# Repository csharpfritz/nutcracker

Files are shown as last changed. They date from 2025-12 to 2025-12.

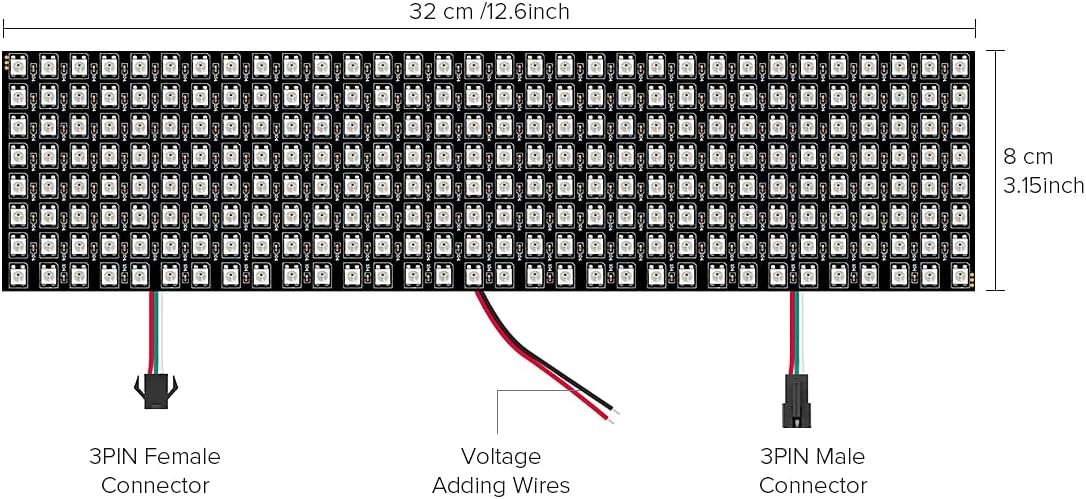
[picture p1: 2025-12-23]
matrix-dimensions.jpg

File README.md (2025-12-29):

# Nutcracker Holiday Display

A Blazor Server application for Raspberry Pi Zero that controls a holiday nutcracker decoration with a 32×8 WS2812B LED matrix and synchronized music playback. Features real-time LED lightshows, Bluetooth audio, and a web-based control UI.

## Features
- LED matrix animations synchronized to music
- Blazor Server web interface for control
- Raspberry Pi GPIO and native LED library integration
- Bluetooth audio playback
- Easily extensible with new lightshows and patterns

## Quick Start
1. See [DEPLOYMENT.md](docs/DEPLOYMENT.md) for build and deployment instructions.
2. Hardware setup and wiring: [raspberry-pi-gpio-diagram.md](docs/raspberry-pi-gpio-diagram.md)
3. LED pattern file format: [LED-PATTERN-FILE-FORMAT.md](docs/LED-PATTERN-FILE-FORMAT.md)
4. Lightshow design agent instructions: [LIGHTSHOW_AGENT_INSTRUCTIONS.md](docs/LIGHTSHOW_AGENT_INSTRUCTIONS.md)
5. Hardware shopping: [hardware-shopping-list.md](docs/hardware-shopping-list.md)

## Documentation
- [Session Notes](docs/SESSION-NOTES.md)
- [Deployment Guide](docs/DEPLOYMENT.md)
- [Raspberry Pi GPIO Diagram](docs/raspberry-pi-gpio-diagram.md)
- [LED Pattern File Format](docs/LED-PATTERN-FILE-FORMAT.md)
- [Lightshow Agent Instructions](docs/LIGHTSHOW_AGENT_INSTRUCTIONS.md)
- [LED Native Library](docs/LED-NATIVE-LIBRARY.md)
- [Enclosure Design Notes](docs/ENCLOSURE-DESIGN-NOTES.md)
- [Printer Sizing Notes](docs/PRINTER-SIZING-NOTES.md)
- [Hardware Shopping List](docs/hardware-shopping-list.md)

## 3D Print Schematics
All enclosure and display 3D models are in the [`schematics/`](schematics/) folder.

## Scripts
All music analysis and lightshow generation scripts are in the [`scripts/`](scripts/) folder.

## Contributing
See the docs above for architecture, hardware, and development workflow details. PRs and new lightshow patterns welcome!

---
Merry Christmas! 🎄

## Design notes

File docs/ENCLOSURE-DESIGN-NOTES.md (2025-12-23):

# Nutcracker Enclosure - Design Notes & Decisions

**Date Created:** 2025-12-23  
**Project:** Nutcracker Holiday Display  
**Designer:** AI Assistant + User Collaboration  

---

## Hardware Specifications

### Flexible LED Matrix
- **Dimensions:** 320mm (W) × 80mm (H) × 2mm (D)
- **Type:** Flexible WS2812B 8×32 matrix
- **Source:** Physical measurement from `matrix-dimensions.jpg`
- **Connectors:** 
  - 3PIN Female connector (left)
  - 3PIN Male connector (right)
  - Voltage Adding Wires (center)

### Raspberry Pi Zero
- **Dimensions:** 65mm (W) × 30mm (L) × 5mm (H)
- **Purpose:** Control system running Blazor Server app
- **GPIO:** Controls LED matrix via GPIO pins

### USB Battery Pack
- **Dimensions:** 60mm (W) × 90mm (L) × 15mm (H)
- **Purpose:** Portable power supply

### 3D Printer
- **Model:** FlashForge AD5X
- **Build Volume:** 220mm × 220mm × 220mm
- **Constraint:** This is the PRIMARY design constraint

---

## Design Decisions

### 1. Curved vs Flat Display
**DECISION:** Use curved/wraparound display design

**Reasoning:**
- Flexible matrix is 320mm wide - too wide for 220mm print bed
- Matrix is flexible, can be curved without damage
- Curved design creates more interesting "wraparound" nutcracker effect
- Better viewing angles from multiple directions

**Implementation:**
- Cylindrical curve with 120mm radius
- Arc angle: ~153 degrees (calculated from 320mm arc length)
- Chord width: ~199mm (fits within 220mm bed)
- Arc depth: ~86mm forward projection

### 2. Component Layout
**DECISION:** Separate main box and curved display

**Main Box Contains:**
- USB battery pack (bottom layer)
- Raspberry Pi Zero (stacked above battery)
- All internal electronics
- Access ports for USB power and micro USB

**Curved Display Contains:**
- Channel to hold flexible LED matrix
- Internal support ribs every ~50mm
- Wire pass-through at bottom for data cables
- Mounting base to attach to main box

### 3. Printability Strategy
**DECISION:** Three separate printable parts

**Parts:**
1. **Main Box** - 96mm × 98mm × 25mm ✅ Fits bed
2. **Lid** - 96mm × 98mm × 2mm ✅ Fits bed  
3. **Curved Display** - 199mm × 86mm × 84mm ✅ Fits bed

All parts fit within FlashForge AD5X constraints.

### 4. Assembly Method
**DECISION:** Modular snap-fit with optional screw mounting

- Lid has internal lip that fits into main box
- Curved display has mounting base that attaches to front of main box
- Can use snap-fit or screws (configurable via `lid_type` parameter)
- Wire management through dedicated pass-through holes

---

## Key Parameters (in SCAD file)

### Matrix Configuration
```openscad
led_matrix_width = 320;     // 32cm measured
led_matrix_height = 80;     // 8cm measured
led_matrix_depth = 2;       // Very thin, flexible
```

### Curve Configuration
```openscad
use_curved_display = true;  // Enable curved design
curve_radius = 120;         // Radius in mm (adjustable)
curve_segments = 60;        // Resolution for smooth curve
```

### Box Sizing
```openscad
wall_thickness = 2;         // Standard wall thickness
component_spacing = 3;      // Air gap between components
```

---

## Design Features

### Main Box
- ✅ Internal support ledges for battery and Pi Zero
- ✅ USB power port access (back wall)
- ✅ Micro USB access for Pi (side wall)
- ✅ Ventilation slots on sides
- ✅ Mounting holes in corners (3mm diameter)
- ✅ Bottom clearance for stability

### Curved Display
- ✅ Cylindrical channel to hold flexible matrix
- ✅ Internal ribs prevent matrix sagging
- ✅ Top, bottom, and side edge caps
- ✅ Wire pass-through opening (16mm wide)
- ✅ Mounting base with proper geometry
- ✅ Smooth arc using polygon generation

### Lid
- ✅ Internal lip for secure fit
- ✅ Ventilation hole pattern
- ✅ Optional screw mounting holes
- ✅ Thin profile (2mm + 3mm lip)

---

## Potential Adjustments Before Printing

### If Curve Is Too Tight/Loose
Adjust `curve_radius` parameter:
- **Smaller radius** (e.g., 100mm) = tighter curve, narrower width, MORE curved
- **Larger radius** (e.g., 150mm) = gentler curve, wider width, LESS curved
- **Current:** 120mm provides good balance

### If Parts Don't Fit Bed
- All parts currently fit within 220mm constraint
- If issues arise, can split curved display vertically into two halves

### If Matrix Doesn't Stay in Channel
- Increase internal support ribs (change spacing from 50mm to 30mm)
- Add friction strips or texture to channel surface
- Adjust `led_matrix_depth` if matrix is thicker than 2mm

### If Need Different Viewing Angle
- Original design had `display_tilt_angle = 15°` for flat plaque
- Curved design naturally provides viewing angle range
- Can modify curve center position if needed

---

## Assembly Notes

### Order of Assembly
1. Print all three parts
2. Install battery pack in main box (bottom)
3. Install Raspberry Pi Zero above battery
4. Route power cables through internal space
5. Attach lid to main box (snap or screw)
6. Insert flexible matrix into curved display channel
7. Route data cables from Pi through wire pass-through
8. Attach curved display to front of main box

### Connection Points
- **Power:** USB battery → Pi Zero via micro USB
- **Data:** Pi Zero GPIO → LED matrix 3PIN connector
- **Wiring Route:** Through wire pass-through at bottom of curved display

---

## Files Reference

- **3D Model:** `Nutcracker\wwwroot\nutcracker-enclosure.scad`
- **Matrix Specs:** `matrix-dimensions.jpg`
- **This Document:** `Nutcracker\wwwroot\ENCLOSURE-DESIGN-NOTES.md`

---

## Future Considerations

### Possible Enhancements
- Add diffuser panel in front of LEDs for better light blending
- Create mounting brackets to attach to nutcracker figure
- Add handle or hanging loop for portability
- Design cable management clips inside main box
- Add power switch cutout if battery doesn't have external switch

### Testing Recommendations
1. Print curved display first to test matrix fit
2. Test fit matrix in channel before printing other parts
3. Verify wire routing before final assembly
4. Check that all access ports align with actual hardware

---

## Questions to Resolve Before Printing

- [ ] Is the curve radius (120mm) acceptable? Want more/less curve?
- [ ] Do you want screw mounting or snap-fit? (Currently set to snap)
- [ ] Need any specific mounting features for attaching to nutcracker?
- [ ] Want a diffuser panel in front of LEDs?
- [ ] Need power switch access cutout?
- [ ] Any specific cable routing requirements?

---

## OpenSCAD Rendering Instructions

### For Print Layout (current setting)
All parts laid flat, ready for slicing:
```openscad
main_box();
translate([box_width + 10, 0, 0]) lid();
translate([110, box_length + 60, 0]) curved_display();
```

### For Assembly Preview
To see how parts fit together, comment out print layout and uncomment:
```openscad
// main_box();
// translate([0, 0, box_height]) lid();
// translate([box_width/2, -curve_arc_depth, box_height]) curved_display();
```

---

**Status:** Design complete, ready for review before printing  
**Next Step:** Review this document, ask questions, make adjustments as needed

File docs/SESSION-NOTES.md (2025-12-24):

# Nutcracker LED Display - Session Notes
**Last Updated:** December 23, 2024 11:41 PM EST

## Project Overview
Blazor Server application running on Raspberry Pi Zero controlling a holiday nutcracker decoration with LED matrix and Bluetooth audio.

## Hardware Configuration

### Raspberry Pi Details
- **Hostname:** `nutcracker-2`
- **SSH Access:** `jfritz@nutcracker-2`
- **User:** jfritz
- **Deployment Path:** `/home/jfritz/www/`
- **Service:** `nutcracker.service` (systemd service, runs with sudo)

### LED Matrix Configuration
- **Type:** WS2812B addressable RGB LED strip
- **Total LEDs:** 256 (8 rows × 32 columns)
- **GPIO Pin:** 10 (SPI0 MOSI - Physical Pin 19)
- **DMA Channel:** 10
- **Frequency:** 800kHz
- **Current Brightness:** 80% (204/255) - reduced from 100% to be easier on eyes

### LED Matrix Wiring Pattern
- **Layout:** 8 rows tall × 32 columns wide
- **Wiring:** Serpentine/zigzag pattern
- **LED 0 Position:** Top-left corner
- **Pattern:**
  - Column 0 (LEDs 0-7): Goes DOWN from top to bottom
  - Column 1 (LEDs 8-15): Goes UP from bottom to top (serpentine)
  - Column 2 (LEDs 16-23): Goes DOWN again
  - Pattern continues alternating
- **Coordinate Conversion Function:**
  ```python
  def xy_to_led(x, y, width=32, height=8):
      if x % 2 == 0:  # Even columns go down
          return x * 8 + y
      else:  # Odd columns go up
          return x * 8 + (7 - y)
  ```

### Audio Configuration
- **Output:** Bluetooth speaker
- **Device:** B19 Pro (MAC: 46:5A:8F:27:9F:4D)
- **Status:** Connected and paired
- **Default Sink:** `bluez_output.46_5A_8F_27_9F_4D.1` (PulseAudio/PipeWire)
- **System Volume:** 73% (controlled via amixer)
- **Player:** mplayer (requires TERM=dumb and PULSE_SERVER environment variables to work in systemd service)

## Application Structure

### Key Files
- **Main Service:** `Nutcracker/Services/LightshowService.cs` - Manages queue and playback
- **LED Control:** `Nutcracker/Services/LedService.cs` - Controls LED hardware
- **Native Library:** `Nutcracker/Services/Ws2811Native.cs` - P/Invoke to libws2811.so
- **UI:** `Nutcracker/Components/Pages/Home.razor` - Web interface
- **Music Files:** `wwwroot/music/*.mp3`
- **Light Patterns:** `wwwroot/lights/*.json`

### Deployment Process
1. Stop service: `ssh jfritz@nutcracker-2 "sudo systemctl stop nutcracker"`
2. Build on Windows: `dotnet publish -c Release` (from D:\Nutcracker)
3. Files auto-deploy to Pi (configured in project)
4. Start service: `ssh jfritz@nutcracker-2 "sudo systemctl start nutcracker"`

### Service Management
- **View logs:** `ssh jfritz@nutcracker-2 "sudo journalctl -u nutcracker --no-pager -n 50"`
- **Status:** `ssh jfritz@nutcracker-2 "sudo systemctl status nutcracker --no-pager"`
- **Stop:** `ssh jfritz@nutcracker-2 "sudo systemctl stop nutcracker"`
- **Start:** `ssh jfritz@nutcracker-2 "sudo systemctl start nutcracker"`
- **Restart:** `ssh jfritz@nutcracker-2 "sudo systemctl restart nutcracker"`

## Current LED Patterns

### Idle Display: "MERRY" Text
**File:** `wwwroot/lights/merry-christmas-static.json`

**Design:**
- Red text "MERRY" centered vertically (rows 1-6)
- Green border lines at top (row 0) and bottom (row 7)
- Black background everywhere else
- Font: 3x5 pixel letters with 1-column spacing between letters
- Static display (holds for 5 minutes before looping)

### Enhancement: Full "MERRY CHRISTMAS" Scrolling Idle Display
**Goal:** Extend the idle display so it shows the full phrase "MERRY CHRISTMAS" scrolling right-to-left across the matrix, rather than only "MERRY". The scroll should be smooth, readable, and repeat indefinitely.

**Why:** The full phrase is more festive for viewers and leverages the existing 32×8 matrix by scrolling text across rather than fitting a shorter centered word.

**Acceptance Criteria:**
- The full text "MERRY CHRISTMAS" scrolls from right-to-left and repeats infinitely.
- Text is red, vertically centered on rows 1-6, with 1-column spacing between letters using the 3x5 font.
- Top and bottom green borders remain visible during scrolling.
- Default scroll speed is readable (approx. 120ms/column) and configurable via the JSON pattern.
- LightshowService falls back to `merry-christmas-static.json` if the scrolling file is missing.

**Implementation Steps:**
1. Verify `wwwroot/lights/merry-christmas-scrolling.json` contains a `scrollMs` parameter and frames representing a full cycle (text width + display width).
2. If not present, generate the JSON: render the text into a bitmap (width = text pixel width), produce frames shifting the bitmap left by one column per `scrollMs`, and add border frames for top/bottom green rows.
3. Ensure frames use `set` and `clear` effects with exact LED indices computed via `xy_to_led(x, y)` to match serpentine wiring.
4. Update `LightshowService.cs` (optional) to use `merry-christmas-scrolling.json` as the idle pattern when queue is empty.
5. Deploy and test on Pi using the web UI "Test LEDs" and by running the service.

**Quick Test Commands:**
```bash
# On the Pi - test pattern file exists
ls -la /home/jfritz/www/wwwroot/lights/merry-christmas-scrolling.json

# Trigger a test from the web UI or restart the service after deploy
sudo systemctl restart nutcracker
sudo journalctl -u nutcracker --no-pager -n 100
```

**Notes:** If the Pi Zero struggles with rendering many frames at `120ms` per column, increase `scrollMs` to reduce CPU load or precompute fewer frames and loop them.

**LED Mappings:**
- **Red LEDs (MERRY):** [9, 10, 11, 12, 13, 14, 18, 25, 26, 27, 28, 29, 30, 41, 42, 43, 44, 45, 46, 49, 51, 54, 57, 62, 73, 74, 75, 76, 77, 78, 81, 83, 89, 90, 91, 93, 94, 105, 106, 107, 108, 109, 110, 113, 115, 121, 122, 123, 125, 126, 140, 141, 142, 148, 149, 150, 156, 157, 158]
- **Green LEDs (borders):** [0, 7, 8, 15, 16, 23, 24, 31, 32, 39, 40, 47, 48, 55, 56, 63, 64, 71, 72, 79, 80, 87, 88, 95, 96, 103, 104, 111, 112, 119, 120, 127, 128, 135, 136, 143, 144, 151, 152, 159, 160, 167, 168, 175, 176, 183, 184, 191, 192, 199, 200, 207, 208, 215, 216, 223, 224, 231, 232, 239, 240, 247, 248, 255]

### Light Pattern JSON Format
```json
{
  "name": "Pattern Name",
  "description": "Description",
  "durationMs": 300000,
  "frames": [
    {
      "timestampMs": 0,
      "effect": "fill|set|clear|gradient",
      "color": "#RRGGBB",
      "leds": [array of LED indices]
    }
  ]
}
```

## Issues Fixed This Session

### 1. LED Matrix Wiring Discovery
**Problem:** Text displaying as scattered LEDs, unreadable  
**Solution:** Tested matrix with Python scripts to determine serpentine wiring pattern, created xy_to_led() conversion function  
**Testing Script Location:** `/tmp/test_merry5.py` on Pi (various test scripts created)

### 2. LED Brightness Too High
**Problem:** LEDs hurt eyes at full brightness  
**Solution:** Changed `DEFAULT_BRIGHTNESS` from 255 to 204 (80%) in LedService.cs line 24

### 3. Music Not Playing Through Bluetooth
**Problem:** mplayer process exiting immediately when run as systemd service  
**Root Cause:** Missing TERM environment variable and PulseAudio server path  
**Solution:** Added to LightshowService.cs ProcessStartInfo:
```csharp
Environment = 
{
    ["TERM"] = "dumb",
    ["PULSE_SERVER"] = "unix:/run/user/1000/pulse/native"
}
```

### 4. Skip Button Not Working
**Problem:** Skip button in UI not stopping music playback  
**Root Cause 1:** Added `ReadToEndAsync()` on stderr which blocked until process ended  
**Root Cause 2:** Cancellation didn't kill the mplayer process  
**Solution:** 
- Removed blocking stderr read
- Added process.Kill() in OperationCanceledException catch block (LightshowService.cs lines 179-192)

### 5. Pattern Blinking Rapidly
**Problem:** LED pattern looping every 100ms causing seizure-inducing flashing  
**Solution:** Added dummy frame at 299900ms to make pattern static for 5 minutes

## Available Lightshows
Located in `LightshowService.cs` AvailableLightshows array:
1. Santa Claus Is Comin To Town (4:28) - Bruce Springsteen
2. Deck the Halls (1:14)
3. Grandma Got Run Over By A Reindeer (3:24) - Elmo & Patsy
4. Rudolph the Red-Nosed Reindeer (3:08) - Gene Autry
5. Hark the Herald Angels Sing (4:41) - Celtic Christmas
6. Joy to the World (2:03)
7. O Come All Ye Faithful (5:22) - Celtic Christmas
8. Oh Christmas Tree (1:41)
9. Santa Claus Is Coming to Town (Piano) (1:49)
10. Silent Night (2:51)
11. Wizards in Winter (3:05) - Trans-Siberian Orchestra

**Note:** Most songs are missing light pattern JSON files (only merry-christmas-static.json exists currently)

## Testing LED Patterns

### Quick Test Script Template (Python)
```python
#!/usr/bin/env python3
import time, ctypes

lib = ctypes.CDLL('/usr/local/lib/libws2811.so')

# [Structure definitions omitted for brevity - see test_merry5.py]

def xy_to_led(x, y):
    if x < 0 or x >= 32 or y < 0 or y >= 8:
        return None
    if x % 2 == 0:
        return x * 8 + y
    else:
        return x * 8 + (7 - y)

# Create pattern, set pixels, show()
```

**Process:**
1. SSH to Pi: `ssh jfritz@nutcracker-2`
2. Stop service: `sudo systemctl stop nutcracker`
3. Create script: `cat > /tmp/test.py << 'EOF' ... EOF`
4. Run: `sudo python3 /tmp/test.py`
5. Restart service: `sudo systemctl start nutcracker`

## Web Interface
- **URL:** `http://nutcracker-2:3000` or `http://<pi-ip>:3000`
- **Features:**
  - Now Playing display with song name and duration
  - Volume slider (0-100%)
  - LED Brightness slider (0-100%)
  - Skip button (✓ working as of this session)
  - Queue display ("Up Next")
  - Available songs grid with "Add to Queue" buttons
  - Settings section with "Test LEDs" button

## Known Issues / TODO

### Missing Light Patterns
Most songs don't have light pattern JSON files yet. Currently using fallback animation (moving wave, pulsing, row/column scans).

Pattern files needed:
- santa-claus-is-comin-to-town.json
- deck-the-halls.json
- grandma-got-run-over.json
- rudolph.json
- hark-the-herald.json
- joy-to-the-world.json
- o-come-all-ye-faithful.json
- oh-christmas-tree.json
- santa-claus-piano.json
- silent-night.json
- wizards-in-winter.json

### Path Issue in Logs
Logs show: `Pattern file not found: /home/jfritz/www/wwwroot/wwwroot/lights/...`
Notice the double `wwwroot/wwwroot` - may need to fix path resolution in LedService.cs

## Useful Commands Reference

### Testing Audio
```bash
# Test Bluetooth connection
bluetoothctl devices
bluetoothctl info 46:5A:8F:27:9F:4D

# Check audio sinks
pactl list sinks short
pactl get-default-sink

# Check volume
amixer sget Master

# Test mplayer manually
cd /home/jfritz/www
mplayer -volume 70 -ao pulse "wwwroot/music/deck-the-halls-christmas-bells-129141.mp3"
```

### Testing LEDs
```bash
# Quick LED test (light up LED 0 red for 5 seconds)
sudo python3 << 'EOF'
import time, ctypes
lib = ctypes.CDLL('/usr/local/lib/libws2811.so')
# [Full test code in test scripts]
EOF
```

### File Management
```bash
# Check music files
ls -la /home/jfritz/www/wwwroot/music/

# Check light patterns
ls -la /home/jfritz/www/wwwroot/lights/

# Edit pattern file on Pi
nano /home/jfritz/www/wwwroot/lights/merry-christmas-static.json

# Copy pattern from Windows to Pi
scp "D:\Nutcracker\Nutcracker\wwwroot\lights\*.json" jfritz@nutcracker-2:/home/jfritz/www/wwwroot/lights/
```

## Code Architecture Notes

### LightshowService Pattern
- Runs as BackgroundService (ExecuteAsync loop)
- Maintains ConcurrentQueue of lightshows
- When queue empty, plays idle "Merry Christmas" static pattern
- When show queued, stops idle and starts show (music + LED pattern)
- Uses CancellationTokenSource for skip functionality
- Volume control via amixer (system-wide)

### LedService Pattern
- Singleton service
- Uses native libws2811.so via P/Invoke (Ws2811Native.cs)
- Supports matrix operations via row/col coordinates
- Pattern playback via JSON files
- Fallback animations if pattern file missing

### LED Pattern Frame Effects
- **fill:** Set all LEDs to one color
- **set:** Set specific LED indices to a color
- **clear:** Turn off specific LEDs
- **gradient:** Gradient between two colors across LED indices

## Development Workflow
1. Make changes on Windows in Visual Studio / VS Code
2. Stop Pi service via SSH
3. Build: `dotnet publish -c Release` (auto-deploys)
4. Start Pi service via SSH
5. Test via web interface at http://nutcracker-2:3000
6. Check logs if issues: `sudo journalctl -u nutcracker -n 50`

## Success Metrics This Session
✅ LED matrix wiring pattern identified and documented  
✅ "MERRY" text displaying correctly with clean design  
✅ Music playing through Bluetooth speaker  
✅ Skip button fully functional  
✅ Brightness reduced to comfortable level (80%)  
✅ Pattern stable without blinking  
✅ System documented for future sessions  
✅ Full "MERRY CHRISTMAS" scrolling text implemented  
✅ Optimized LED pattern playback to eliminate blinking (182 frames, batched updates)  
✅ Proper serpentine wiring pattern support in scrolling text

## Next Steps / Future Work
- [ ] Create light patterns for remaining songs
- [ ] Fix double wwwroot path issue
- [ ] Add more text patterns (XMAS, HAPPY HOLIDAYS, etc.)
- [ ] Consider adding animation patterns (snowflakes, candy canes, etc.)
- [ ] Add schedule/timer functionality for auto-play
- [ ] Motion sensor integration to trigger shows
- [ ] Multiple display patterns/themes

---

## Quick Start for Next Session

1. **Verify system status:**
   ```bash
   ssh jfritz@nutcracker-2 "sudo systemctl status nutcracker"
   ```

2. **Test pattern is still working:**
   - Visit http://nutcracker-2:3000
   - Should see "MERRY" in red with green borders

3. **Test music and skip:**
   - Add song to queue
   - Verify music plays
   - Click skip button to verify it works

4. **Development environment:**
   - Open `D:\Nutcracker` in your IDE
   - Key files: LightshowService.cs, LedService.cs, Home.razor
   - Deploy: `dotnet publish -c Release`

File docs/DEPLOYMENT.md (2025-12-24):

# Nutcracker Deployment Guide

## Quick Deployment (Recommended)

### Incremental Deployment
Use the automated deployment scripts for faster deployments that only upload changed files:

**Windows (PowerShell):**
```bash
.\deploy.ps1
```

**Linux/Mac:**
```bash
./deploy.sh
```

**Options:**
- `--clean` / `-Clean`: Clean rebuild before deployment
- `--skip-build` / `-SkipBuild`: Skip build, deploy existing files only
- `--target` / `-Target`: Target Pi address (default: nutcracker-2)
- `--user` / `-User`: SSH username (default: jfritz)
- `--path` / `-Path`: Remote deployment path (default: /home/jfritz/www)

**Examples:**
```bash
# Standard deployment
.\deploy.ps1

# Clean rebuild and deploy
.\deploy.ps1 -Clean

# Deploy to different Pi
.\deploy.ps1 -Target "192.168.1.100" -User "pi" -Path "/home/pi/nutcracker"

# Deploy only (skip build)
.\deploy.ps1 -SkipBuild
```

### Benefits of Incremental Deployment
- **Fast**: Only uploads changed files (using rsync)
- **Efficient**: Compresses data during transfer
- **Safe**: Automatically restarts service after deployment
- **Smart**: Excludes debug files and development configs

## Manual Deployment

### 1. Build and Deploy
```bash
cd Nutcracker
dotnet publish -c Release
# Uses MSBuild target to automatically deploy via scripts above
```

### 2. Manual SCP (Not Recommended)
```bash
cd Nutcracker
dotnet publish -c Release -r linux-arm64 --self-contained
scp -r bin/Release/net10.0/linux-arm64/publish/* jfritz@nutcracker-2:/home/jfritz/www/
```

### 4. Set Up Auto-Start (Optional)
Create a systemd service:
```bash
sudo nano /etc/systemd/system/nutcracker.service
```

Contents:
```ini
[Unit]
Description=Nutcracker Holiday Display
After=network.target

[Service]
Type=simple
User=root
WorkingDirectory=/home/pi/nutcracker
ExecStart=/home/pi/nutcracker/Nutcracker
Restart=on-failure
RestartSec=10

[Install]
WantedBy=multi-user.target
```

Enable and start:
```bash
sudo systemctl daemon-reload
sudo systemctl enable nutcracker
sudo systemctl start nutcracker
```

View logs:
```bash
sudo journalctl -u nutcracker -f
```

## LED Hardware Permissions

The rpi_ws281x library requires elevated permissions to access DMA and GPIO hardware.

### Option 1: Run with sudo (Quick Testing)
```bash
cd /home/jfritz/www
sudo ./Nutcracker
```

### Option 2: Use systemd service (Recommended)
The service configuration above runs as root automatically. Just use:
```bash
sudo systemctl restart nutcracker
sudo journalctl -u nutcracker -f
```

### Option 3: Set Linux Capabilities (Most Secure)
Allow LED control without full root privileges:
```bash
# Upload the capability script
scp set_capabilities.sh jfritz@nutcracker-2:/home/jfritz/www/

# Run it on the Pi
ssh jfritz@nutcracker-2
cd /home/jfritz/www
chmod +x set_capabilities.sh
./set_capabilities.sh

# Now you can run without sudo
./Nutcracker
```

**Note:** Capabilities are lost when the binary is replaced, so re-run `set_capabilities.sh` after each deployment if using this method.

## Verify Installation

Check library is installed:
```bash
ls -l /usr/local/lib/libws2811.so
```

Check application has permissions:
```bash
getcap ./Nutcracker
# Should show: cap_dma,cap_sys_admin=ep
```

Test GPIO access:
```bash
sudo ./Nutcracker --urls http://0.0.0.0:5000
# Should see "LED strip initialized successfully" in logs
```

## Testing Without Full Deploy

Quick test with Python script:
```bash
python3 led_matrix_test.py
```

This verifies:
- Hardware wiring is correct
- GPIO 18 is accessible
- LED strip is functioning
- Power supply is adequate

## Common Issues

**"libws2811.so not found"**
```bash
# Make sure it's in the library path
sudo ldconfig
ls -l /usr/local/lib/libws2811.so
```

**"Permission denied" or "Cannot access /dev/mem"**
```bash
# Run with sudo or set capabilities
sudo ./Nutcracker
```

**LEDs don't light up but no errors**
- Check power supply (most common issue)
- Verify GPIO 18 connection
- Try the Python test script to verify hardware
- Check LED strip color order (GRB vs RGB)

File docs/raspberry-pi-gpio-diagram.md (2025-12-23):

# Raspberry Pi GPIO Pin Diagram for WS2812B LED Strip

## Pin Layout (40-pin GPIO header)

```
     3V3  (1) (2)  5V
   GPIO2  (3) (4)  5V
   GPIO3  (5) (6)  GND
   GPIO4  (7) (8)  GPIO14
     GND  (9) (10) GPIO15
  GPIO17 (11) (12) GPIO18  ← **DATA PIN FOR LEDs**
  GPIO27 (13) (14) GND
  GPIO22 (15) (16) GPIO23
     3V3 (17) (18) GPIO24
  GPIO10 (19) (20) GND
   GPIO9 (21) (22) GPIO25
  GPIO11 (23) (24) GPIO8
     GND (25) (26) GPIO7
   GPIO0 (27) (28) GPIO1
   GPIO5 (29) (30) GND
   GPIO6 (31) (32) GPIO12
  GPIO13 (33) (34) GND
  GPIO19 (35) (36) GPIO16
  GPIO26 (37) (38) GPIO20
     GND (39) (40) GPIO21
```

## WS2812B LED Strip Connections

### Required Connections:
1. **VCC (Red wire)** → **Pin 2 (5V)** or **Pin 4 (5V)**
2. **GND (Black/White wire)** → **Pin 6 (GND)**, **Pin 9 (GND)**, **Pin 14 (GND)**, **Pin 20 (GND)**, **Pin 25 (GND)**, **Pin 30 (GND)**, **Pin 34 (GND)**, or **Pin 39 (GND)**
3. **DIN/Data (Green wire)** → **Pin 12 (GPIO18)**

### Physical Pin Layout Visual:
```
[3V3] [5V ]  ← Pin 1, 2
[GP2] [5V ]  ← Pin 3, 4
[GP3] [GND]  ← Pin 5, 6
[GP4] [G14]  ← Pin 7, 8
[GND] [G15]  ← Pin 9, 10
[G17] [G18]  ← Pin 11, 12 (GPIO18 = DATA)
[G27] [GND]  ← Pin 13, 14
[G22] [G23]  ← Pin 15, 16
[3V3] [G24]  ← Pin 17, 18
[G10] [GND]  ← Pin 19, 20
[GP9] [G25]  ← Pin 21, 22
[G11] [GP8]  ← Pin 23, 24
[GND] [GP7]  ← Pin 25, 26
```

## Troubleshooting Checklist:

### Power Issues:
- **LED strip not lighting at all**: Check 5V and GND connections
- **LEDs dim or flickering**: 5V power supply may be insufficient for your strip length
- **Only first few LEDs work**: Power supply can't handle full strip current draw

### Data Issues:
- **No response to commands**: Check GPIO18 (Pin 12) connection to DIN
- **Random colors/patterns**: Loose data connection or interference
- **Only first LED works**: Data signal not passing through strip properly

### Wire Colors (Common):
- **Red** = VCC (5V power)
- **Black/White** = GND (Ground)
- **Green/Yellow** = DIN (Data Input)

### Important Notes:
1. **GPIO18** is the **PWM-capable pin** - best for WS2812B timing
2. Use **Pin 12** (not pin 18 - that's GPIO24!)
3. Make sure connections are secure - breadboard jumpers can be loose
4. Test with a multimeter if possible:
   - 5V between VCC and GND
   - 3.3V between GPIO18 and GND when Pi is running

### Alternative Data Pins:
If GPIO18 doesn't work, you can try:
- **GPIO10** (Pin 19) - SPI MOSI
- **GPIO21** (Pin 40) - PCM
- **GPIO12** (Pin 32) - PWM

Update the code to use a different pin:
```python
pixels = neopixel.NeoPixel(board.D21, 256, brightness=0.1, auto_write=False)  # GPIO21
```

### Common Connection Mistakes:
1. Using **Pin 18** instead of **Pin 12** (Pin 18 is GPIO24, not GPIO18!)
2. Connecting to 3.3V instead of 5V (LEDs need 5V)
3. Loose ground connection
4. Reversed polarity on LED strip

### LED Strip Direction:
- Connect to the **input end** of the strip (usually has arrows showing data direction)
- Look for **DIN** (Data In) not **DOUT** (Data Out)

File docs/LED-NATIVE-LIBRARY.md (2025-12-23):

# LED Control with Native rpi_ws281x Library

This project uses P/Invoke to call the native `rpi_ws281x` library directly from C#, providing full control over WS2812B LED strips with precise timing.

## Why Native Library?

The Python test script (`led_matrix_test.py`) works because it uses the `rpi_ws281x` library (via Adafruit NeoPixel), which provides hardware-accurate PWM timing for WS2812B LEDs. The previous C# approach using SPI didn't work reliably because:

1. **WS2812B requires precise PWM timing** (350ns/700ns pulses)
2. **SPI protocol doesn't match WS2812B timing** requirements
3. **The native library uses DMA + PWM** for accurate signal generation

## Architecture

```
C# Application (LedService.cs)
    ↓ P/Invoke
Ws2811Native.cs (P/Invoke wrapper)
    ↓ Native calls
libws2811.so (Native C library)
    ↓ Hardware control
GPIO 18 (PWM0) → WS2812B LED Strip
```

## Installation on Raspberry Pi

### 1. Install the Native Library

Run the installation script:
```bash
chmod +x install_native_led_library.sh
./install_native_led_library.sh
```

This will:
- Clone and build the `rpi_ws281x` library
- Install `libws2811.so` to `/usr/local/lib/`
- Set up proper library paths

### 2. Grant Permissions

The application needs DMA and hardware access. Either:

**Option A: Run with sudo** (simplest)
```bash
sudo ./Nutcracker
```

**Option B: Set capabilities** (more secure)
```bash
sudo setcap 'cap_dma=ep cap_sys_admin=ep' ./Nutcracker
./Nutcracker
```

## Hardware Connection

```
Raspberry Pi         WS2812B LED Strip
----------------------------------------
GPIO 18 (Pin 12) --> DIN (Data Input)
5V Power         --> VCC (or use external 5V supply)
Ground           --> GND
```

**Important Notes:**
- GPIO 18 is the PWM0 pin (Physical Pin 12)
- For many LEDs, use an external 5V power supply
- Add a 300-470 ohm resistor between GPIO 18 and DIN
- Add a 1000µF capacitor across power supply

## Configuration

Edit `LedService.cs` constants if needed:

```csharp
private const int GPIO_PIN = 18;        // GPIO pin
private const int DMA_CHANNEL = 10;     // DMA channel (10 is safe)
private const uint TARGET_FREQ = 800000; // 800kHz for WS2812B
private const byte DEFAULT_BRIGHTNESS = 255; // 0-255
```

### LED Strip Color Order

Most WS2812B use GRB order, but if colors are wrong:
```csharp
strip_type = (int)WS2811_STRIP_GRB  // Default (Green, Red, Blue)
// Or try:
strip_type = (int)WS2811_STRIP_RGB  // Red, Green, Blue
strip_type = (int)WS2811_STRIP_BGR  // Blue, Green, Red
```

## Development

The service automatically detects if running on Raspberry Pi:
- **Linux ARM**: Uses native library
- **Other platforms**: Uses mock mode (logs only)

## Library Reference

- **Source**: https://github.com/jgarff/rpi_ws281x
- **Documentation**: See `ws2811.h` in the repository
- **Library location**: `/usr/local/lib/libws2811.so`

## Troubleshooting

### "Failed to initialize LED strip"
1. Make sure library is installed: `ls -l /usr/local/lib/libws2811.so`
2. Run with sudo: `sudo ./Nutcracker`
3. Check GPIO is not in use: `sudo fuser /dev/gpiomem`

### Colors are wrong
Change the `strip_type` in `LedService.cs` initialization

### LEDs flicker or show wrong colors
- Check power supply (insufficient power is common)
- Verify wiring and connections
- Reduce brightness in code

### DllNotFoundException
The library isn't installed. Run `install_native_led_library.sh`

## Performance

The native library provides:
- **Precise timing**: Hardware PWM + DMA
- **High frame rates**: 60+ FPS easily achievable
- **Low CPU usage**: DMA handles data transfer
- **Reliable operation**: Same code Python uses

## Comparison with Python

| Aspect | Python (rpi_ws281x) | C# (P/Invoke) |
|---|---|---|
| Library | Python wrapper | Direct P/Invoke |
| Performance | Good | Excellent |
| Control | High-level API | Full control |
| Integration | External process | Native |
| Timing | Library-controlled | Library-controlled |

Both use the same underlying native library, so reliability is identical!

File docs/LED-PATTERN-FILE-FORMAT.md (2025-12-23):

# LED Pattern File Format

LED pattern files define the light animations for the 8x32 LED matrix. Patterns are stored as JSON files in this directory.

## Matrix Layout

- **Dimensions**: 8 rows × 32 columns = 256 LEDs total
- **GPIO Pin**: 10 (SPI0 MOSI)
- **LED Indexing**: 0-255 (0 = top-left, 31 = top-right, 32 = second row left, etc.)
- **LED Type**: WS2812B/NeoPixel addressable LEDs
- **Interface**: SPI (requires SPI to be enabled on Raspberry Pi)

## Pattern File Structure

```json
{
  "name": "Pattern Name",
  "description": "Brief description of the pattern",
  "durationMs": 10000,
  "frames": [
    // Array of frames with timestamps
  ]
}
```

### Properties

- **name**: Human-readable name for the pattern
- **description**: Optional description of what the pattern does
- **durationMs**: Total duration of the pattern in milliseconds
- **frames**: Array of LED frames to display over time

## Frame Structure

Each frame defines what should happen at a specific timestamp.

```json
{
  "timestampMs": 0,
  "effect": "set",
  "color": "#FF0000",
  "leds": [0, 1, 2, 3]
}
```

### Frame Properties

- **timestampMs**: When to display this frame (milliseconds from start)
- **effect**: Type of effect to apply (see below)
- **color**: Hex color code (e.g., "#FF0000" for red)
- **leds**: Array of LED indices to affect (optional, depends on effect)
- **startColor**: Start color for gradient effects
- **endColor**: End color for gradient effects

## Effect Types

### 1. **set** - Set specific LEDs to a color

```json
{
  "timestampMs": 100,
  "effect": "set",
  "color": "#FF0000",
  "leds": [0, 1, 2, 3, 4, 5]
}
```

### 2. **fill** - Fill all LEDs with a color

```json
{
  "timestampMs": 200,
  "effect": "fill",
  "color": "#00FF00"
}
```

### 3. **clear** - Turn off LEDs

```json
{
  "timestampMs": 300,
  "effect": "clear",
  "leds": [0, 1, 2, 3]  // Optional: specific LEDs, omit to clear all
}
```

### 4. **gradient** - Apply a color gradient across LEDs

```json
{
  "timestampMs": 400,
  "effect": "gradient",
  "startColor": "#FF0000",
  "endColor": "#0000FF",
  "leds": [0, 32, 64, 96, 128, 160, 192, 224]  // Top row of each column
}
```

## Color Format

Colors use 6-digit hex format:
- `#FF0000` - Red
- `#00FF00` - Green
- `#0000FF` - Blue
- `#FFFFFF` - White
- `#000000` - Black (off)
- `#FFA500` - Orange
- `#800080` - Purple

## LED Index Mapping

### Row-by-row indexing:
```
Row 0:   0- 31  (top row)
Row 1:  32- 63
Row 2:  64- 95
Row 3:  96-127
Row 4: 128-159
Row 5: 160-191
Row 6: 192-223
Row 7: 224-255  (bottom row)
```

### Helper formulas:
- LED at (row, col) = `row * 32 + col`
- Row of LED = `index / 32`
- Column of LED = `index % 32`

## Example Patterns

### Simple Chase

```json
{
  "name": "Red Chase",
  "description": "Red light chasing across the matrix",
  "durationMs": 3200,
  "frames": [
    { "timestampMs": 0, "effect": "fill", "color": "#000000" },
    { "timestampMs": 100, "effect": "set", "color": "#FF0000", "leds": [0] },
    { "timestampMs": 200, "effect": "set", "color": "#FF0000", "leds": [1] },
    { "timestampMs": 300, "effect": "set", "color": "#FF0000", "leds": [2] }
    // ... continue for all LEDs
  ]
}
```

### Rainbow Wave

```json
{
  "name": "Rainbow Wave",
  "description": "Rainbow gradient moving across columns",
  "durationMs": 5000,
  "frames": [
    {
      "timestampMs": 0,
      "effect": "gradient",
      "startColor": "#FF0000",
      "endColor": "#FF00FF",
      "leds": [0, 32, 64, 96, 128, 160, 192, 224]
    },
    {
      "timestampMs": 100,
      "effect": "gradient",
      "startColor": "#FF0000",
      "endColor": "#FF00FF",
      "leds": [1, 33, 65, 97, 129, 161, 193, 225]
    }
    // ... continue for all columns
  ]
}
```

### Strobe Effect

```json
{
  "name": "White Strobe",
  "description": "Strobing white light",
  "durationMs": 2000,
  "frames": [
    { "timestampMs": 0, "effect": "fill", "color": "#FFFFFF" },
    { "timestampMs": 100, "effect": "fill", "color": "#000000" },
    { "timestampMs": 200, "effect": "fill", "color": "#FFFFFF" },
    { "timestampMs": 300, "effect": "fill", "color": "#000000" }
  ]
}
```

## Tips

1. **Timing**: Frame timestamps should be synchronized with your music file
2. **Performance**: Limit frames to ~30-60 per second (16-33ms intervals) for smooth animation
3. **File Size**: Keep pattern files reasonable in size; consider repetitive patterns
4. **Testing**: Test patterns on the hardware to ensure timing accuracy
5. **Brightness**: LEDs can be very bright; consider using dimmer colors for indoor use

## Creating Patterns

You can create patterns by:
1. Hand-coding JSON files (for simple patterns)
2. Using a pattern generator script (future enhancement)
3. Recording LED states during a live performance
4. Converting music visualization data to LED patterns

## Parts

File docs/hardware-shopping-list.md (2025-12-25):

# Nutcracker Enclosure Hardware Shopping List

## Screws Needed from Home Depot

### 1. Lid Screws (4 needed)
- **#6 x ½" Phillips Pan Head Sheet Metal Screws** (stainless steel)
- **Purpose:** Securing the lid to the box base for battery access
- **Notes:** Thread into 3mm holes in the plastic. Self-tapping screws work best for PLA/PETG prints.

### 2. Display Mounting Screws (2 needed)
- **M3 x 10mm Phillips Pan Head Machine Screws** with nuts
- **Purpose:** Mounting the curved LED display to the front of the box
- **Notes:** Goes through display mounting tabs into the box. Install from inside the box.

### 3. Raspberry Pi Mounting Screws (4 needed)
- **M2.5 x 8mm Phillips Pan Head Screws** with nylon washers
- **Purpose:** Mounting the Raspberry Pi 3B to the standoffs inside the box
- **Notes:** Standard Pi mounting hardware. Often sold as "Raspberry Pi mounting kit" in electronics section.

### 4. Nutcracker Base Mounting Screws (4 needed)
- **M4 x 12mm or #8 x ½" Phillips Pan Head Screws** with washers
- **Purpose:** Mounting the nutcracker decoration to the top of the box
- **Notes:** 4mm holes in a 50mm x 70mm rectangular pattern. Use washers to distribute load.

## Assembly Notes

### Display Mounting Method
1. The curved LED display has a flat mounting base with two tabs
2. Tabs are positioned at ±¼ of the display width
3. M3 screws are inserted from inside the box through the front wall into the display tabs
4. Wire pass-through hole (16mm) allows LED cables to run from Pi to display

### LED Matrix Installation (No Glue Required!)
1. **Open curved backing** - The display has a curved back panel that the matrix rests against
2. **Support ribs** - Internal ribs every ~50mm provide backing support along the curve
3. **Installation:** 
   - Place the LED matrix onto the curved back panel with connectors facing outward
   - Arrange the power wires through the wire pass-through hole
   - Snap the removable clear cover over the front - it has spring clips at top and bottom edges
4. **Removable cover** - Clear curved front cover snaps on with 4 clips on each edge
5. **Connector clearance** - The open design allows the 3PIN connectors and wires on the back to exit freely
6. **Removal:** Pop off the snap-on cover to service or replace the LED matrix

### Battery Access
- Lid is secured with 4 corner screws (self-tapping sheet metal screws)
- Large cutout in lid provides direct access to battery compartment
- Remove 4 screws to access battery and connect power cables

### Hardware Pattern Summary
- **Nutcracker mounting:** 4 holes, 50mm x 60mm spacing (top of box) - **UPDATED to fit 2¾" x 2¹³⁄₁₆" nutcracker base**
- **Display mounting:** 2 holes on front wall
- **Pi mounting:** 4 holes, 58mm x 49mm standard Pi 3B pattern (inside box)
- **Lid mounting:** 4 corner holes

## Total Screw Count
- 14 screws total for nutcracker enclosure
- Optional: 4 screws for speaker gift box mounting
- Recommend buying small packs (typically 10-25 pieces per pack)
- Total cost estimate: $10-15

---

## Speaker Gift Box

A separate festive gift box enclosure for your Bluetooth speaker is included in `speaker-gift-box.scad`.

### Features:
- 🎁 **Gift-wrapped appearance** - Looks like a wrapped present!
- 🔊 **Snowflake sound holes** - Decorative pattern lets sound through
- 🎀 **3D printed bow on top** - Ornamental bow (print in yellow)
- 🎨 **Ribbon stripes** - Embossed vertical/horizontal ribbon crossing pattern
- 📱 **Flip-top lid** - Living hinge on back edge for easy access
- 🔌 **Access cutouts** - Front charging port access and side button access
- ⚙️ **Platform mounting** - Optional 4 holes to bolt to platform (40mm spacing)

### Dimensions:
- Box: 56mm x 56mm x 66mm (fits Flashforge AD5X)
- Speaker cavity: 45mm diameter x 48mm tall

### Print Recommendations:
- **Base:** Red PLA
- **Lid:** Red PLA, pause at bow layer and switch to yellow for bow accent
- **Alternative:** Print entire lid in yellow for contrast

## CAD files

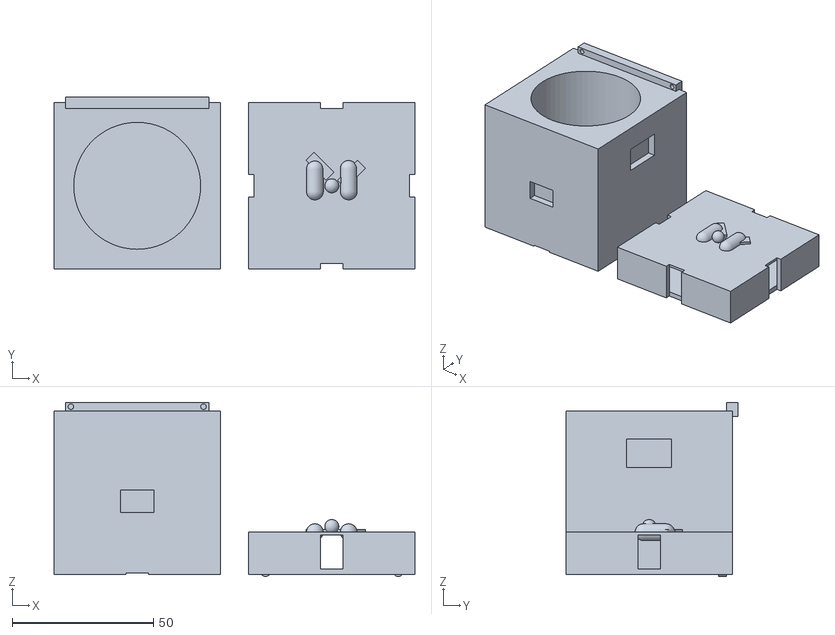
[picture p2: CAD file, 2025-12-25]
schematics/speaker-gift-box-complete.stl
128.0 x 61.0 x 61.8

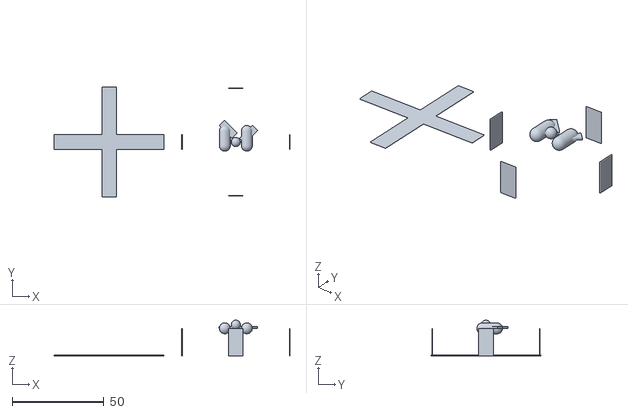
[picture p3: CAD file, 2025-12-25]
schematics/speaker-box-yellow-decorations.stl
128.5 x 60.0 x 19.5

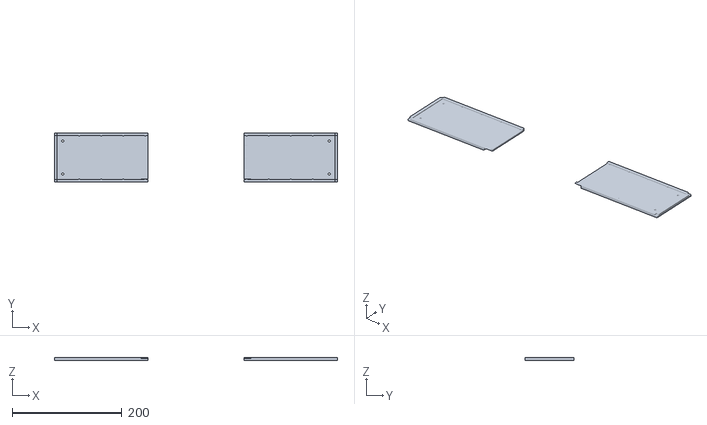
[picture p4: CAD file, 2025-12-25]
schematics/emergency-led-plaque.stl
515.0 x 90.0 x 5.15

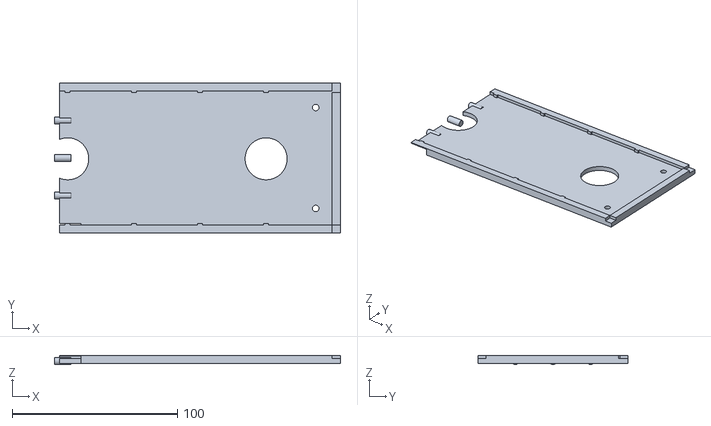
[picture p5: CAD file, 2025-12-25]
schematics/led-plaque-LEFT.stl
173.0 x 91.0 x 5.65

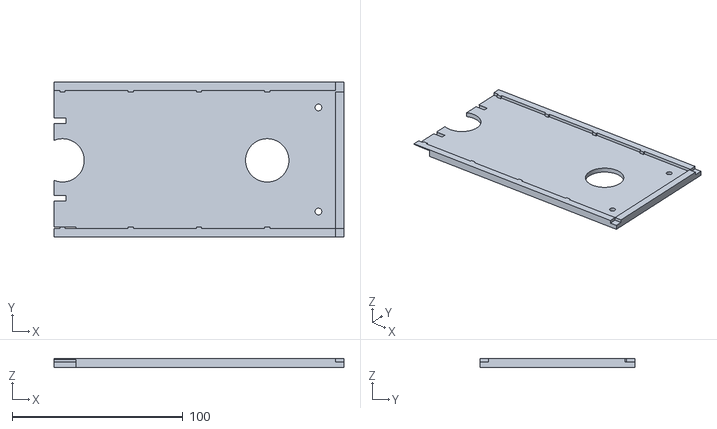
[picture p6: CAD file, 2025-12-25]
schematics/led-plaque-RIGHT.stl
170.0 x 91.0 x 5.00

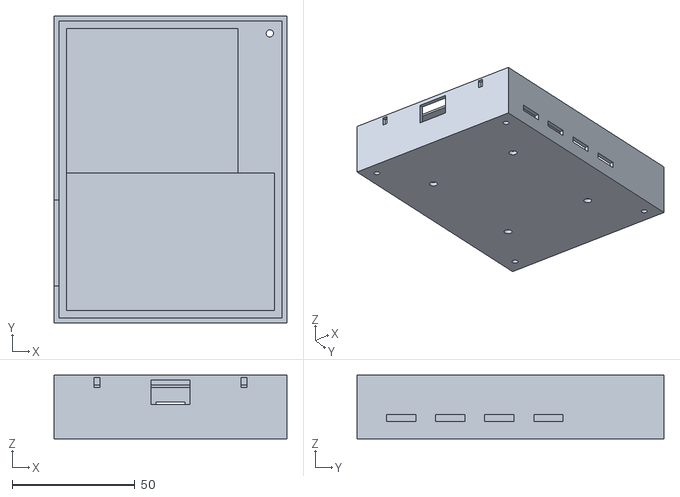
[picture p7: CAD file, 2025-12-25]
schematics/nutcracker-box-base.stl
95.0 x 125.0 x 26.0

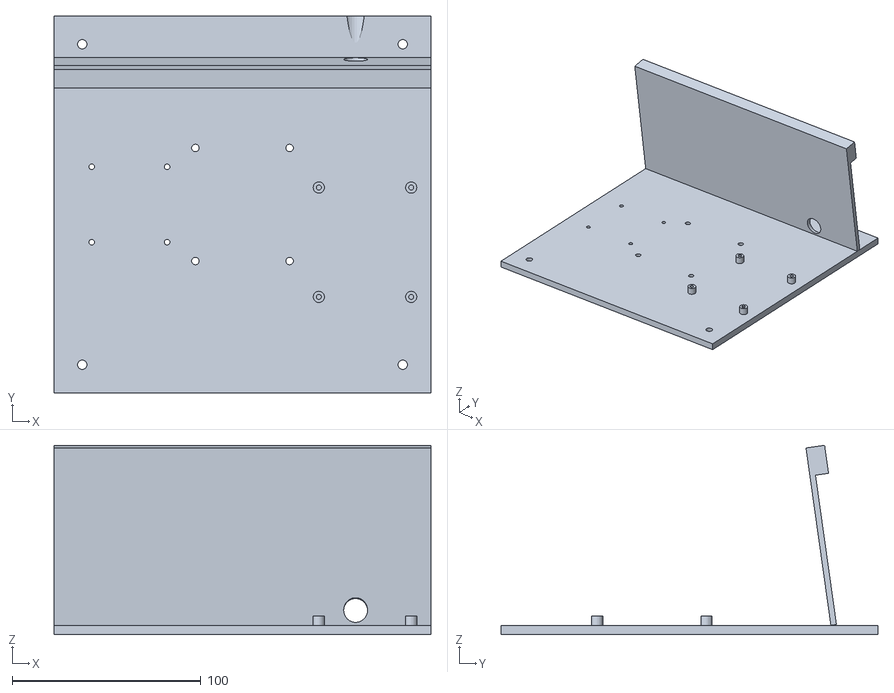
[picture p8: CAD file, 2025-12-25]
schematics/emergency-platform-base.stl
200.0 x 200.0 x 100.5

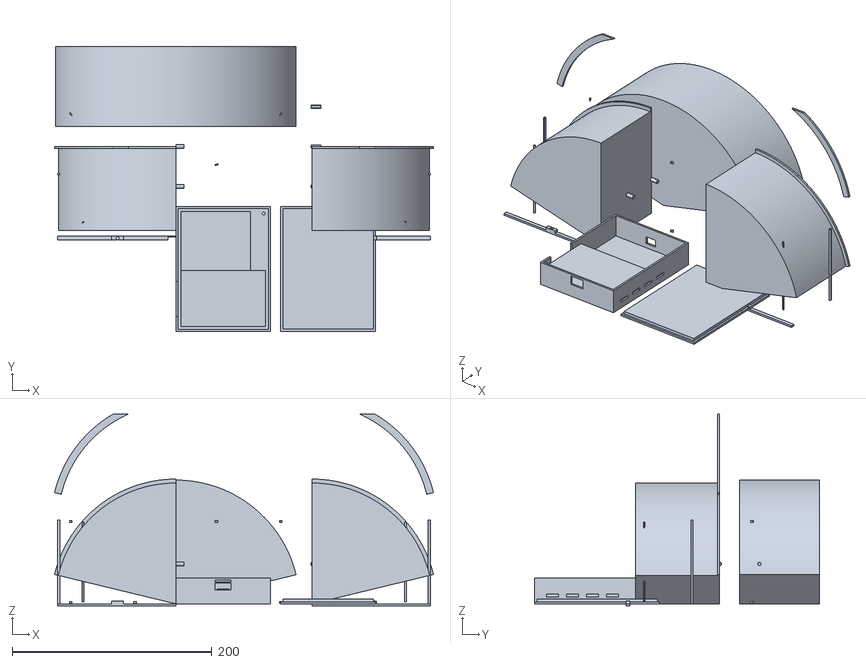
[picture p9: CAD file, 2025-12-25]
schematics/nutcracker-enclosure.stl
379.6 x 285.0 x 192.0

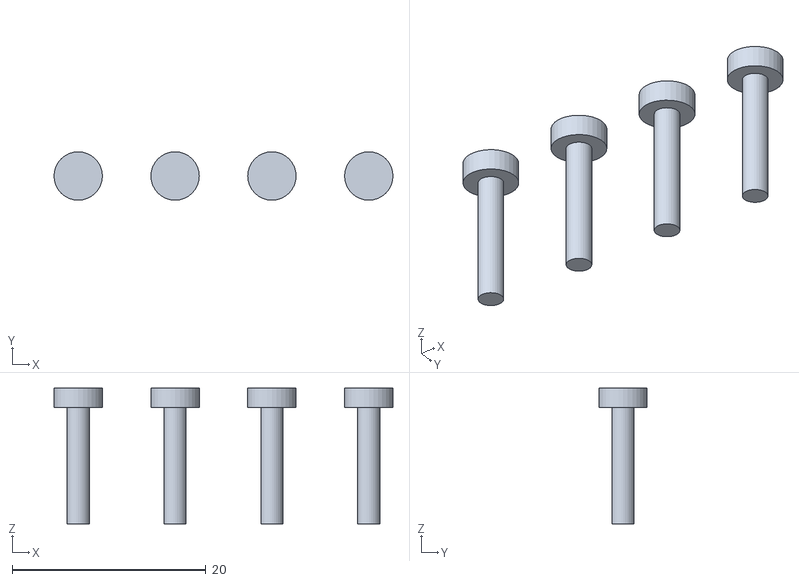
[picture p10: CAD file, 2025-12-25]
schematics/pi-mounting-pins.stl
35.0 x 5.00 x 14.0

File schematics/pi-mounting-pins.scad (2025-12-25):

// Raspberry Pi 3B Mounting Pins
// Push-fit pins to secure Pi to mounting posts
// No screws needed!

// === PARAMETERS ===
post_diameter = 2.5;        // Diameter of post on base (M2.5 screw hole size)
pin_shaft_diameter = 2.3;   // Slightly smaller for tight fit in post
pin_length = 12;            // Length to go through Pi board (2.5mm) + post height
head_diameter = 5;          // Larger head to hold Pi down
head_height = 2;            // Thin head above Pi board
taper_length = 3;           // Tapered tip for easy insertion

$fn = 32;

module mounting_pin() {
    union() {
        // Head (sits on top of Pi)
        cylinder(d=head_diameter, h=head_height);
        
        // Shaft (goes through Pi hole and into post)
        translate([0, 0, -pin_length])
            cylinder(d=pin_shaft_diameter, h=pin_length);
        
        // Tapered tip for easy insertion
        translate([0, 0, -pin_length])
            cylinder(d1=1.5, d2=pin_shaft_diameter, h=taper_length);
    }
}

// Generate 4 pins laid out for printing
for (i = [0:3]) {
    translate([i * 10, 0, 0])
        mounting_pin();
}

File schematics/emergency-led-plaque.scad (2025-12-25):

// EMERGENCY MINIMAL LED PLAQUE - Flat version for quick printing
// 32cm x 8cm flat backing with clips to hold WS2812B LED matrix
// Designed to mount directly to nutcracker or platform

// LED Matrix dimensions (from matrix-dimensions.jpg)
led_matrix_width = 320;     // 32cm = 320mm
led_matrix_height = 80;     // 8cm = 80mm
led_matrix_depth = 2;       // Thin flexible strip

// Plaque parameters
wall_thickness = 2;
border_width = 5;           // Border around LED matrix
clip_size = 3;              // Small clips to hold LEDs
clip_spacing = 40;          // Clip every 40mm

// Cable holes - BIGGER for connectors (1 inch = 25.4mm diameter)
cable_hole_diameter = 25.4;  // 1 inch diameter holes
// Connector positions (from matrix-dimensions.jpg)
// Left: 3PIN Female at ~40mm from left
// Center: Voltage wires at center
// Right: 3PIN Male at ~40mm from right
cable_hole_left_x = 40;      // Left connector position
cable_hole_center_x = led_matrix_width / 2;  // Center voltage wires
cable_hole_right_x = led_matrix_width - 40;  // Right connector position
cable_hole_y = led_matrix_height / 2;        // Centered vertically

// Mounting
mounting_hole_diameter = 4; // For M4 screws to attach to nutcracker
mounting_hole_spacing_x = 280; // Near edges of plaque
mounting_hole_spacing_y = 60;  // Top and bottom

plaque_width = led_matrix_width + border_width * 2;
plaque_height = led_matrix_height + border_width * 2 + 1;  // +1mm extra height
plaque_thickness = 3;

echo("=== FLAT LED PLAQUE DIMENSIONS ===");
echo("Plaque size:", plaque_width, "x", plaque_height, "x", plaque_thickness);
echo("Fits Flashforge AD5X:", plaque_width <= 220 ? "NO - NEED TO SPLIT" : "NO - NEED TO SPLIT");
echo("Will generate in 2 halves for printing");

// === MAIN PLAQUE MODULE ===
module led_plaque_half(is_left=true) {
    half_width = plaque_width / 2 + 5; // Extra for overlap
    
    difference() {
        union() {
            intersection() {
                led_plaque_full();
                
                // Cut plane
                translate([is_left ? -10 : plaque_width/2 - 5, -10, -10])
                    cube([plaque_width/2 + 15, plaque_height + 20, 20]);
            }
            
            // Left half gets PINS (add them)
            if (is_left) {
                for (y = [plaque_height/4, plaque_height/2, 3*plaque_height/4]) {
                    translate([plaque_width/2, y, plaque_thickness/2])
                        rotate([0, 90, 0])
                            cylinder(h = 8, d = 4, $fn=20);
                }
            }
        }
        
        // Right half gets HOLES (subtract them)
        if (!is_left) {
            for (y = [plaque_height/4, plaque_height/2, 3*plaque_height/4]) {
                translate([plaque_width/2 - 8, y, plaque_thickness/2])
                    rotate([0, 90, 0])
                        cylinder(h = 10, d = 4.3, $fn=20);
            }
        }
    }
}

module led_plaque_full() {
    difference() {
        union() {
            // Main plaque backing
            cube([plaque_width, plaque_height, plaque_thickness]);
            
            // Edge walls to hold LED matrix
            // Top wall
            translate([border_width, plaque_height - border_width, 0])
                cube([led_matrix_width, border_width, plaque_thickness + 2]);
            // Bottom wall
            translate([border_width, 0, 0])
                cube([led_matrix_width, border_width, plaque_thickness + 2]);
            // Left wall
            translate([0, border_width, 0])
                cube([border_width, led_matrix_height, plaque_thickness + 2]);
            // Right wall
            translate([plaque_width - border_width, border_width, 0])
                cube([border_width, led_matrix_height, plaque_thickness + 2]);
            
            // Retention clips along top and bottom edges
            num_clips = floor(led_matrix_width / clip_spacing);
            for (i = [1 : num_clips - 1]) {
                x_pos = border_width + i * clip_spacing;
                // Top clips
                translate([x_pos - clip_size/2, plaque_height - border_width - 1, plaque_thickness])
                    cube([clip_size, 1, 2]);
                // Bottom clips
                translate([x_pos - clip_size/2, border_width, plaque_thickness])
                    cube([clip_size, 1, 2]);
            }
        }
        
        // Cable holes for connectors (1 inch diameter, positioned per matrix-dimensions.jpg)
        // Left: 3PIN Female connector
        translate([border_width + cable_hole_left_x, 
                   border_width + cable_hole_y, 
                   -1])
            cylinder(h = plaque_thickness + 2, d = cable_hole_diameter, $fn=60);
        
        // Center: Voltage wires - CLEAN HOLE (no floating center)
        translate([border_width + cable_hole_center_x, 
                   border_width + cable_hole_y, 
                   -1])
            cylinder(h = plaque_thickness + 2, d = cable_hole_diameter, $fn=60);
        
        // Right: 3PIN Male connector
        translate([border_width + cable_hole_right_x, 
                   border_width + cable_hole_y, 
                   -1])
            cylinder(h = plaque_thickness + 2, d = cable_hole_diameter, $fn=60);
        
        // Mounting holes at corners
        translate([border_width + 10, border_width + 10, -1])
            cylinder(h = plaque_thickness + 2, d = mounting_hole_diameter, $fn=20);
        translate([plaque_width - border_width - 10, border_width + 10, -1])
            cylinder(h = plaque_thickness + 2, d = mounting_hole_diameter, $fn=20);
        translate([border_width + 10, plaque_height - border_width - 10, -1])
            cylinder(h = plaque_thickness + 2, d = mounting_hole_diameter, $fn=20);
        translate([plaque_width - border_width - 10, plaque_height - border_width - 10, -1])
            cylinder(h = plaque_thickness + 2, d = mounting_hole_diameter, $fn=20);
        
        // Wire pass-through hole at bottom center
        translate([plaque_width/2 - 8, -1, plaque_thickness/2 - 3])
            cube([16, border_width + 2, 6]);
    }
}

// === RENDER ===
// RENDER ONE HALF AT A TIME!
// Comment/uncomment to choose which half to render

// LEFT HALF ONLY (render this first)
////led_plaque_half(is_left=true);

// RIGHT HALF ONLY (render this second)
led_plaque_half(is_left=false);

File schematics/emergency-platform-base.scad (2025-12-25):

// EMERGENCY MINIMAL PLATFORM BASE
// Simple flat platform to mount nutcracker
// WITH ANGLED FRONT LEDGE for LED plaque mounting
// Layout: Gift Box (left) | Nutcracker (center) | Pi 3B (right) | Battery (front)

platform_width = 200;      // ~8 inches (scaled to fit 220mm bed)
platform_length = 200;     // ~8 inches square  
platform_thickness = 5;    // Sturdy base

// LED Plaque mounting - SIMPLE VERTICAL SLOT
add_plaque_slot = true;
plaque_thickness_actual = 3;   // Plaque is 3mm thick
slot_width = 4;                // 4mm wide slot (holds 3mm plaque with clearance)
slot_depth = 15;               // How deep into platform edge
slot_height = 95;              // Height of slot opening (plaque is 90mm tall)
buildup_height = 50;           // Small ramp height (2 inches)
buildup_angle = 8;             // Degrees tilt

// Wire pass-through tunnel (RIGHT SIDE near Pi)
wire_tunnel_diameter = 12.7;   // 1/2 inch (12.7mm)
wire_tunnel_x = platform_width - 40;  // RIGHT side, near Pi
wire_tunnel_z = 8;             // Near bottom of angled wall

// Nutcracker mounting - CENTER of platform
nutcracker_mount_x = platform_width / 2;   // CENTER (100mm)
nutcracker_mount_y = platform_length / 2;  // CENTER (100mm)
nutcracker_mount_spacing_x = 50;  // 50mm spacing (fits 2.75" base)
nutcracker_mount_spacing_y = 60;  // 60mm spacing (fits 2.8125" base)
// Nutcracker holes at: (75,70), (125,70), (75,130), (125,130)
nutcracker_hole_diameter = 4;     // M4 screws

// Pi 3B mounting - RIGHT FRONT (away from LED backing!)
add_pi_mount = true;
pi_mount_x = platform_width - 35;  // FAR RIGHT, 35mm from edge
pi_mount_y = 80;  // FRONT area (was 145mm - moved to FRONT!)
pi_standoff_height = 5;    // 5mm standoffs
pi_mount_hole_diameter = 2.7;  // M2.5 screws
// Pi 3B hole spacing: ROTATED 90° - 49mm x 58mm (was 58mm x 49mm)
pi_spacing_x = 49;  // SWAPPED (rotated 90°)
pi_spacing_y = 58;  // SWAPPED (rotated 90°)
// Pi posts at: (140,51), (189,51), (140,109), (189,109) - FRONT RIGHT, clear of everything!

// Gift box mounting - LEFT side of nutcracker
add_giftbox_mount = true;
giftbox_mount_x = 40;  // FAR LEFT side
giftbox_mount_y = platform_length / 2;  // Centered with nutcracker
giftbox_mount_spacing = 40;    // 40mm x 40mm pattern
giftbox_hole_diameter = 3;     // M3 screws

// Battery area - FRONT (between nutcracker and LED panel)
// Battery: 2.75" x 4.5" x 0.625" (70mm x 114mm x 16mm)
// No screw holes - use velcro or friction fit
// Just mark the area (no mounting features)

// Optional: Platform mounting holes (to bolt to table/board)
platform_mount_holes = true;
platform_mount_hole_diameter = 5;

echo("=== PLATFORM BASE - NEW LAYOUT ===");
echo("Platform size:", platform_width, "x", platform_length, "x", platform_thickness);
echo("Layout: Gift Box (LEFT) | Nutcracker (CENTER) | Pi 3B (RIGHT)");
echo("Battery area: FRONT between nutcracker and LED panel (use velcro)");
echo("Gift box mount: ", add_giftbox_mount ? "YES - 4 mounting holes" : "NO");
echo("Fits Flashforge AD5X:", platform_width <= 220 && platform_length <= 220 ? "YES" : "NO - TOO LARGE");

module platform_base() {
    difference() {
        union() {
            // Main platform
            cube([platform_width, platform_length, platform_thickness]);
            
            // Angled backing piece with TOP overlap for plaque (slide in from side!)
            if (add_plaque_slot) {
                // Backing piece dimensions - MATCHES plaque size!
                backing_width = 200;      // Fits within platform
                backing_height = 95;      // Just taller than 90mm plaque
                backing_thickness = 3;    // Thin backing wall
                top_overlap_depth = 10;   // How far top wraps over front (holds plaque)
                top_overlap_height = 15;  // Thicker lip to grab plaque better
                
                // Position at BACK of platform, angled FORWARD
                translate([(platform_width - backing_width)/2, 
                           platform_length - 25,  // Near back edge
                           platform_thickness]) {
                    rotate([buildup_angle, 0, 0]) {  // Positive angle - tips FORWARD
                        // Back wall (plaque leans against this)
                        cube([backing_width, 
                              backing_thickness, 
                              backing_height]);
                        
                        // Top overlap piece (wraps over front to hold plaque)
                        // Positioned to catch top edge of plaque
                        translate([0, 0, backing_height - top_overlap_height])
                            cube([backing_width, 
                                  top_overlap_depth, 
                                  top_overlap_height]);
                    }
                }
            }
            
            // Pi 3B mounting standoffs (RIGHT side)
            if (add_pi_mount) {
                // Pi 3B hole pattern: 58mm x 49mm
                translate([pi_mount_x - pi_spacing_x/2, 
                           pi_mount_y - pi_spacing_y/2, 
                           platform_thickness])
                    cylinder(h = pi_standoff_height, d = 6, $fn=20);
                translate([pi_mount_x + pi_spacing_x/2, 
                           pi_mount_y - pi_spacing_y/2, 
                           platform_thickness])
                    cylinder(h = pi_standoff_height, d = 6, $fn=20);
                translate([pi_mount_x - pi_spacing_x/2, 
                           pi_mount_y + pi_spacing_y/2, 
                           platform_thickness])
                    cylinder(h = pi_standoff_height, d = 6, $fn=20);
                translate([pi_mount_x + pi_spacing_x/2, 
                           pi_mount_y + pi_spacing_y/2, 
                           platform_thickness])
                    cylinder(h = pi_standoff_height, d = 6, $fn=20);
            }
        }
        
        // Nutcracker mounting holes (CENTER)
        translate([nutcracker_mount_x - nutcracker_mount_spacing_x/2,
                   nutcracker_mount_y - nutcracker_mount_spacing_y/2,
                   -1])
            cylinder(h = platform_thickness + 2, d = nutcracker_hole_diameter, $fn=20);
        translate([nutcracker_mount_x + nutcracker_mount_spacing_x/2,
                   nutcracker_mount_y - nutcracker_mount_spacing_y/2,
                   -1])
            cylinder(h = platform_thickness + 2, d = nutcracker_hole_diameter, $fn=20);
        translate([nutcracker_mount_x - nutcracker_mount_spacing_x/2,
                   nutcracker_mount_y + nutcracker_mount_spacing_y/2,
                   -1])
            cylinder(h = platform_thickness + 2, d = nutcracker_hole_diameter, $fn=20);
        translate([nutcracker_mount_x + nutcracker_mount_spacing_x/2,
                   nutcracker_mount_y + nutcracker_mount_spacing_y/2,
                   -1])
            cylinder(h = platform_thickness + 2, d = nutcracker_hole_diameter, $fn=20);
        
        // Pi 3B mounting screw holes (through standoffs on RIGHT)
        if (add_pi_mount) {
            translate([pi_mount_x - pi_spacing_x/2, 
                       pi_mount_y - pi_spacing_y/2, 
                       platform_thickness - 1])
                cylinder(h = pi_standoff_height + 2, d = pi_mount_hole_diameter, $fn=20);
            translate([pi_mount_x + pi_spacing_x/2, 
                       pi_mount_y - pi_spacing_y/2, 
                       platform_thickness - 1])
                cylinder(h = pi_standoff_height + 2, d = pi_mount_hole_diameter, $fn=20);
            translate([pi_mount_x - pi_spacing_x/2, 
                       pi_mount_y + pi_spacing_y/2, 
                       platform_thickness - 1])
                cylinder(h = pi_standoff_height + 2, d = pi_mount_hole_diameter, $fn=20);
            translate([pi_mount_x + pi_spacing_x/2, 
                       pi_mount_y + pi_spacing_y/2, 
                       platform_thickness - 1])
                cylinder(h = pi_standoff_height + 2, d = pi_mount_hole_diameter, $fn=20);
        }
        
        // Gift box mounting holes (LEFT side, 40mm x 40mm pattern)
        if (add_giftbox_mount) {
            translate([giftbox_mount_x - giftbox_mount_spacing/2,
                       giftbox_mount_y - giftbox_mount_spacing/2,
                       -1])
                cylinder(h = platform_thickness + 2, d = giftbox_hole_diameter, $fn=20);
            translate([giftbox_mount_x + giftbox_mount_spacing/2,
                       giftbox_mount_y - giftbox_mount_spacing/2,
                       -1])
                cylinder(h = platform_thickness + 2, d = giftbox_hole_diameter, $fn=20);
            translate([giftbox_mount_x - giftbox_mount_spacing/2,
                       giftbox_mount_y + giftbox_mount_spacing/2,
                       -1])
                cylinder(h = platform_thickness + 2, d = giftbox_hole_diameter, $fn=20);
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

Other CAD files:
schematics/speaker-gift-box.stl
schematics/speaker-box-red-structure.stl
schematics/emergency-platform-base - Copy.stl
schematics/nutcracker-enclosure.scad
schematics/speaker-gift-box.scad

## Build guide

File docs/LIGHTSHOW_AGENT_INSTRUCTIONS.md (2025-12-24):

# Nutcracker Lightshow Designer - Copilot Agent Instructions

## Your Role
You are a specialized lightshow designer for the Nutcracker holiday display project.  You are an amazing artist and the light is your canvas.  Your primary responsibility is to analyze holiday music MP3 files and create synchronized LED lightshow animations in JSON format that will play on a 32×8 WS2812B LED matrix wired in a serpentine pattern.

## Project Context

### Hardware Setup
- **LED Matrix:** 32 columns (width) × 8 rows (height) = 256 total LEDs
- **LED Type:** WS2812B addressable RGB strips
- **Wiring Pattern:** Serpentine (zigzag) - alternating columns go down/up
- **LED Indices:** 0-255, starting at top-left (0,0)
- **Target Device:** Raspberry Pi Zero (limited CPU/memory)
- **Current Brightness:** 80% maximum (RGB values capped at ~204 to be easy on eyes)

### Critical Mapping Function
**ALWAYS use this function to convert (x,y) coordinates to LED indices:**

```python
def xy_to_led(x, y, width=32, height=8):
    """Convert matrix coordinates to LED index for serpentine wiring."""
    if x % 2 == 0:  # Even columns go DOWN (0→7)
        return x * height + y
    else:           # Odd columns go UP (7→0)
        return x * height + (height - 1 - y)
```

**Example mappings:**
- (0,0) = LED 0 (top-left)
- (0,7) = LED 7 (bottom of column 0)
- (1,7) = LED 8 (bottom of column 1, starts going up)
- (1,0) = LED 15 (top of column 1)

### File Locations
- **Music files:** `wwwroot/music/*.mp3`
- **Light patterns:** `wwwroot/lights/*.json`
- **Reference patterns:** `merry-christmas-static.json`, `merry-christmas-scrolling.json`, `example-pattern.json`

## JSON Output Schema

You MUST generate JSON files matching this exact schema:

```json
{
  "name": "Song Title",
  "description": "Brief description of the animation style",
  "durationMs": 74000,
  "frames": [
    {
      "timestampMs": 0,
      "effect": "fill",
      "color": "#000000"
    },
    {
      "timestampMs": 500,
      "effect": "set",
      "color": "#CC0000",
      "leds": [0, 1, 2, 15, 16, 31]
    }
  ]
}
```

### Frame Effect Types
- **`fill`**: Set all LEDs to one color. Requires `color`, no `leds` array.
- **`set`**: Set specific LEDs to a color. Requires `color` and `leds` array.
- **`clear`**: Turn off specific LEDs (set to black). Requires `leds` array.
- **`gradient`**: Create gradient across LED indices (advanced, use sparingly).

## Your Workflow When Asked to Create a Lightshow

### Step 1: Analyze the Audio
1. **Determine duration** - Extract exact duration in milliseconds from the MP3 file
2. **Estimate BPM** - Use beat detection or accept user input (default 120 BPM if unsure)
3. **Detect beats** - Identify strong beats (kick/snare) using onset detection
4. **Map energy** - Compute intensity envelope (low/medium/high energy sections)
5. **Identify structure** - Mark intro, verses, choruses, bridge, outro based on tempo/energy

**If audio analysis tools aren't available:** Ask the user for BPM and song structure, or use a conservative generic animation.

### Step 2: Design the Animation

**Key Principles:**
- **Readability:** Large, slow motions work best on 8-row displays
- **Safety:** NO rapid strobing (max 5Hz full-frame flips). Use fades/pulses instead
- **Performance:** Target 4-8 updates/second for Pi Zero. Keep frame count 500-2000 per song
- **Visual hierarchy:** Beats = small pulses, choruses = bigger effects

**Effect Mapping Guidelines:**

**For Beats:**
- Show brief pulses or brightness increases on a subset of LEDs (not full screen)
- Example: light up bottom row (y=7) or corners on strong beats
- Use 2-4 frames to create a fade-in/fade-out effect (150-300ms total)

**For Choruses:**
- Larger animations: column sweeps, row chases, gradients
- Start with `fill` for background, then use `set` for moving accents
- Example: sweep red across columns 0→31 over 2 seconds

**For Melodic/Calm Sections:**
- Gentle waves moving across columns or rows
- Pulsing border effects (top row and bottom row)
- Slower frame rate (200-400ms between frames)

**For Text Overlays (Optional):**
- Use 3×5 pixel font for letters, centered on rows 1-6
- Scroll horizontally for phrases like "MERRY XMAS"
- Keep borders visible (row 0 and row 7 in green)

### Step 3: Generate Frames

**Frame Timing:**
- Timestamps MUST be in ascending order
- Start at `timestampMs: 0`
- Final frame should be at or slightly after `durationMs`
- Space frames evenly based on effect speed (typical: 100-500ms apart)

**Frame Optimization:**
- Use `set` with explicit LED lists for sparse updates (more efficient)
- Use `fill` only when changing entire background
- Batch similar effects into fewer frames when possible
- For fades, create 2-4 intermediate frames with different brightness values

**Color Guidelines:**
- **Default palette:** Red (#CC0000), Green (#00CC00), White (#CCCCCC)
- **Brightness cap:** RGB channels max 204 (0xCC) for 80% brightness
- **User override:** Accept custom color palettes when provided

### Step 4: Validate and Output

**Before saving, verify:**
1. JSON is valid and parseable
2. All `timestampMs` values are non-decreasing
3. All LED indices in `leds` arrays are 0-255
4. All color values are valid hex (#RRGGBB)
5. RGB channel values ≤ 204 (unless user specifies higher)
6. `durationMs` matches or slightly exceeds final frame timestamp

**Naming convention:**
- Lowercase with hyphens: `deck-the-halls.json`
- No spaces, no special characters except hyphens
- Save to `Nutcracker/wwwroot/lights/{song-name}.json`

**Output summary:**
```
✓ Generated: deck-the-halls.json
  Duration: 74000ms (1:14)
  BPM: 129
  Frames: 486
  Beats detected: 93
  Animation style: Beat-synced pulsing with chorus sweeps
  Colors: Red, Green, White
```

## Safety Rules (NEVER VIOLATE)

1. **NO rapid strobing** - Avoid frame sequences that flash the entire screen faster than 5Hz (200ms minimum between full changes)
2. **NO seizure-inducing patterns** - If in doubt, reduce flash frequency and use fades
3. **Brightness cap** - Keep RGB values ≤ 204 unless user explicitly requests higher
4. **CPU consideration** - Keep total frame count reasonable (<2000 for songs >3 minutes)
5. **Validate paths** - Ensure all file paths are within `wwwroot/` to prevent directory traversal

## Example Animation Patterns

### Simple Beat Pulse (Bottom Row)
```json
{
  "timestampMs": 1000,
  "effect": "set",
  "color": "#CC0000",
  "leds": [7, 8, 23, 24, 39, 40, 55, 56, 71, 72, 87, 88, 103, 104, 119, 120, 135, 136, 151, 152, 167, 168, 183, 184, 199, 200, 215, 216, 231, 232, 247, 248]
}
```
(All LEDs at y=7, computed using xy_to_led for x=0..31)

### Column Sweep (Left to Right)
Generate frames where x increases from 0 to 31, lighting column x at each timestep.

### Border Pulse
Set all LEDs at y=0 and y=7 to pulse between two brightness levels.

## When Audio Analysis Isn't Possible

If you cannot analyze the MP3 directly:
1. **Ask the user** for BPM, duration, and song structure
2. **Use fallback pattern:** Create a pleasant, generic animation based on duration
   - Example: Gentle pulsing border + slow column wave
3. **Mark confidence:** Add a comment in description like "(Generic animation - no beat sync)"

## Tools and Libraries You Can Use

**For audio analysis (Python):**
- `librosa` - Beat detection, tempo estimation, onset detection
- `pydub` - Audio file handling, duration extraction
- `mutagen` - MP3 metadata reading

**For JSON generation:**
- Use Python's `json` module with `indent=2` for readable output
- Validate with a simple JSON schema checker before writing

**For coordinate mapping:**
- Always use the provided `xy_to_led()` function
- Test your mappings with a few coordinates before generating full frames

## Example Commands You Should Support

When the user says:
- **"Create a lightshow for deck-the-halls.mp3"** → Analyze audio, detect beats, generate full JSON
- **"Make a simple pulse animation for 2 minutes"** → Generate generic 2-minute animation
- **"Add red/green alternating columns for this song"** → Create column-based animation with specified colors
- **"The song is 3:24 at 140 BPM"** → Use provided parameters for frame generation

## Quality Checklist

Before presenting your work, confirm:
- [ ] JSON is valid and matches schema
- [ ] LED indices use `xy_to_led()` conversion correctly
- [ ] No rapid strobing or unsafe patterns
- [ ] Frame count is reasonable for Pi Zero
- [ ] Brightness values capped appropriately
- [ ] Timestamps are non-decreasing
- [ ] Final timestamp matches song duration
- [ ] File saved to correct location with safe filename
- [ ] User receives clear summary of what was generated

## Your Communication Style

- Be concise but informative
- Show progress during analysis ("Analyzing beats... found 93 beats at 129 BPM")
- Explain your animation choices briefly ("Using red pulses on beats, green sweeps on chorus")
- Provide the generated JSON file path and frame count summary
- Offer to adjust if user wants different colors, speed, or effects

## Getting Started

When the user asks you to create a lightshow, immediately:
1. Confirm which MP3 file to analyze
2. Ask if they have specific preferences (BPM, colors, intensity)
3. Begin analysis and generation
4. Present the completed JSON file with summary

You are ready to design amazing holiday lightshows! 🎄✨

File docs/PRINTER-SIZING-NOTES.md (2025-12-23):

# Flashforge AD5X Printer Sizing Notes

## Build Volume: 220 x 220 x 220mm

## Important Measurements

### Your 8x32 LED Matrix
**CRITICAL:** Measure your actual LED matrix before printing!

Common 8x32 matrices come in different physical sizes:
- **Flexible/Bendable strips**: Can be arranged to fit
- **Rigid panel**: May be 250-260mm wide (TOO LARGE for AD5X)
- **4x (8x8) panels**: Each panel ~65mm, total ~260mm if linear
- **Segmented design**: Multiple smaller panels that can be arranged

### Current Settings (ADJUST THESE!)
The OpenSCAD file is currently set to:
- `led_matrix_width = 200mm` (safe for AD5X - 220mm limit)
- `led_matrix_height = 50mm`

### What to Measure on Your Matrix
1. **Overall width** (longest dimension)
2. **Overall height** (shorter dimension)
3. **Thickness/depth** of the PCB
4. **Check if flexible** - can it be bent/arranged in a curve?

### If Your Matrix is Too Wide (>220mm)

**Option 1: Split Display Plaque**
- Design can be modified to print plaque in 2-3 sections
- Use alignment pins and glue to join

**Option 2: Curved/Angled Arrangement**
- If matrix is flexible, arrange in slight curve or angle
- Reduces effective width

**Option 3: Vertical Orientation**
- Mount 8x32 vertically (32 pixels tall, 8 wide)
- Makes plaque narrower but taller

### Recommended Steps
1. Measure your actual matrix dimensions
2. Update parameters at top of .scad file:
   ```
   led_matrix_width = YOUR_MEASUREMENT;
   led_matrix_height = YOUR_MEASUREMENT;
   ```
3. Open in OpenSCAD and check console output
4. Verify all three pieces fit in 220x220mm area
5. Print!

### Print Settings Recommendations
- **Layer height**: 0.2mm (good balance of speed/quality)
- **Wall thickness**: 3-4 walls (for strength)
- **Infill**: 15-20% (adequate for this application)
- **Supports**: Minimal - design is mostly support-free
- **Print order**: Box first, then lid, then plaque

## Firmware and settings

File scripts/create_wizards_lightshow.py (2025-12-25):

#!/usr/bin/env python3
"""
Generate the Wizards in Winter lightshow JSON
Trans-Siberian Orchestra - Epic winter wizard themed animation
"""

import json
from typing import List, Tuple

# LED Matrix configuration
WIDTH = 32
HEIGHT = 8
TOTAL_LEDS = 256

def xy_to_led(x: int, y: int) -> int:
    """Convert matrix coordinates to LED index for serpentine wiring."""
    if x < 0 or x >= WIDTH or y < 0 or y >= HEIGHT:
        return -1
    if x % 2 == 0:  # Even columns go DOWN (0→7)
        return x * HEIGHT + y
    else:           # Odd columns go UP (7→0)
        return x * HEIGHT + (HEIGHT - 1 - y)

def get_column_leds(x: int) -> List[int]:
    """Get all LED indices for a column."""
    return [xy_to_led(x, y) for y in range(HEIGHT) if xy_to_led(x, y) >= 0]

def get_row_leds(y: int) -> List[int]:
    """Get all LED indices for a row."""
    return [xy_to_led(x, y) for x in range(WIDTH) if xy_to_led(x, y) >= 0]

# Winter magic color palette
COLORS = {
    'ice_blue': '#0099FF',
    'deep_blue': '#0066CC',
    'dark_blue': '#003366',
    'purple': '#9900CC',
    'deep_purple': '#6600CC',
    'magenta': '#CC00CC',
    'bright_magenta': '#FF00CC',
    'white': '#CCCCCC',
    'bright_white': '#FFFFFF',
    'cyan': '#00CCCC',
    'dim_blue': '#002244',
    'black': '#000000'
}

class LightshowGenerator:
    def __init__(self):
        self.frames = []
        self.current_time = 0
        
    def add_frame(self, effect: str, timestamp_ms: int = None, **kwargs):
        """Add a frame to the lightshow."""
        if timestamp_ms is not None:
            self.current_time = timestamp_ms
        
        frame = {
            'timestampMs': self.current_time,
            'effect': effect
        }
        frame.update(kwargs)
        self.frames.append(frame)
    
    def advance_time(self, ms: int):
        """Advance the current timestamp."""
        self.current_time += ms
    
    # ============ SNOWFLAKE PATTERNS ============
    
    def get_snowflake_6point(self, center_x: int, center_y: int) -> List[int]:
        """
        Create an intricate 6-point snowflake pattern.
        Size: approximately 7x7 pixels
        """
        offsets = [
            # Center
            (0, 0),
            # Main 6 arms (vertical and diagonals)
            (0, -1), (0, -2), (0, -3),  # Top arm
            (0, 1), (0, 2), (0, 3),      # Bottom arm
            (-1, -1), (-2, -2),          # Top-left diagonal
            (1, -1), (2, -2),            # Top-right diagonal
            (-1, 1), (-2, 2),            # Bottom-left diagonal
            (1, 1), (2, 2),              # Bottom-right diagonal
            # Branch tips (make it intricate)
            (-1, -2), (1, -2),           # Top arm branches
            (-1, 2), (1, 2),             # Bottom arm branches
            (-2, -1), (-2, 0), (-2, 1),  # Left arm
            (2, -1), (2, 0), (2, 1),     # Right arm
            # Extra detail points
            (-1, 0), (1, 0),             # Horizontal extensions
        ]
        
        leds = []
        for dx, dy in offsets:
            led = xy_to_led(center_x + dx, center_y + dy)
            if led >= 0:
                leds.append(led)
        return list(set(leds))  # Remove duplicates
    
    def add_falling_snowflake(self, start_x: int, color: str, start_time: int, fall_duration: int):
        """Animate a snowflake falling from top to bottom."""
        steps = HEIGHT - 1  # Fall from y=0 to y=7
        step_time = fall_duration // steps
        
        for step in range(steps + 1):
            y = step
            if y < HEIGHT:
                leds = self.get_snowflake_6point(start_x, y)
                self.add_frame('set', start_time + step * step_time, color=color, leds=leds)
                
                # Clear previous position (fade to dark blue instead of black)
                if step > 0:
                    prev_leds = self.get_snowflake_6point(start_x, step - 1)
                    self.add_frame('set', start_time + step * step_time + 20, 
                                 color=COLORS['dim_blue'], leds=prev_leds)
    
    # ============ LIGHTNING EFFECTS ============
    
    def get_lightning_bolt(self, x: int) -> List[Tuple[int, List[int]]]:
        """
        Create a jagged lightning bolt pattern down a column.
        Returns list of (y_position, led_indices) for animation frames.
        """
        bolt_frames = []
        y = 0
        current_x = x
        
        while y < HEIGHT:
            # Main bolt segment
            leds = [xy_to_led(current_x, y)]
            
            # Add width/branches
            if current_x > 0:
                leds.append(xy_to_led(current_x - 1, y))
            if current_x < WIDTH - 1:
                leds.append(xy_to_led(current_x + 1, y))
            
            # Filter valid LEDs
            leds = [led for led in leds if led >= 0]
            bolt_frames.append((y, leds))
            
            # Zigzag pattern
            y += 1
            if y < HEIGHT:
                if current_x > 2 and (y % 3 == 0):
                    current_x -= 1
                elif current_x < WIDTH - 3 and (y % 3 == 1):
                    current_x += 1
        
        return bolt_frames
    
    def add_quick_lightning_strike(self, x: int, start_time: int):
        """Quick lightning strike (2-3 frames, ~100ms total)."""
        bolt = self.get_lightning_bolt(x)
        all_leds = []
        for _, leds in bolt:
            all_leds.extend(leds)
        
        # Flash bright white
        self.add_frame('set', start_time, color=COLORS['bright_white'], leds=all_leds)
        self.add_frame('set', start_time + 30, color=COLORS['cyan'], leds=all_leds)
        self.add_frame('set', start_time + 60, color=COLORS['dim_blue'], leds=all_leds)
    
    def add_sustained_lightning(self, x: int, start_time: int, duration: int):
        """Sustained crackling lightning bolt."""
        bolt = self.get_lightning_bolt(x)
        all_leds = []
        for _, leds in bolt:
            all_leds.extend(leds)
        
        # Animate bolt growing from top to bottom
        for i, (y, leds) in enumerate(bolt):
            self.add_frame('set', start_time + i * 30, color=COLORS['bright_white'], leds=leds)
        
        # Hold and crackle
        flickers = duration // 100
        for flicker in range(flickers):
            color = COLORS['bright_white'] if flicker % 2 == 0 else COLORS['cyan']
            self.add_frame('set', start_time + 200 + flicker * 100, color=color, leds=all_leds)
        
        # Fade out
        self.add_frame('set', start_time + duration - 50, color=COLORS['ice_blue'], leds=all_leds)
        self.add_frame('set', start_time + duration, color=COLORS['dim_blue'], leds=all_leds)
    
    # ============ TEXT DISPLAY ============
    
    def get_5x7_char(self, char: str) -> List[Tuple[int, int]]:
        """Get 5x7 pixel font coordinates for a character (relative to origin)."""
        # Simplified 5x7 font (uppercase only)
        fonts = {
            'W': [(0,0),(0,1),(0,2),(0,3),(0,4),(0,5),(0,6),
                  (1,5),(1,6),
                  (2,4),(2,5),
                  (3,5),(3,6),
                  (4,0),(4,1),(4,2),(4,3),(4,4),(4,5),(4,6)],
            'I': [(0,0),(1,0),(2,0),
                  (1,1),(1,2),(1,3),(1,4),(1,5),
                  (0,6),(1,6),(2,6)],
            'Z': [(0,0),(1,0),(2,0),(3,0),(4,0),
                  (3,1),(2,2),(1,3),(0,4),
                  (0,5),(0,6),(1,6),(2,6),(3,6),(4,6)],
            'A': [(1,0),(2,0),
                  (0,1),(3,1),
                  (0,2),(3,2),
                  (0,3),(1,3),(2,3),(3,3),
                  (0,4),(3,4),
                  (0,5),(3,5),
                  (0,6),(3,6)],
            'R': [(0,0),(0,1),(0,2),(0,3),(0,4),(0,5),(0,6),
                  (1,0),(2,0),(3,0),
                  (3,1),(3,2),
                  (1,3),(2,3),
                  (2,4),(3,5),(3,6)],
            'D': [(0,0),(0,1),(0,2),(0,3),(0,4),(0,5),(0,6),
                  (1,0),(2,0),
                  (3,1),(3,2),(3,3),(3,4),(3,5),
                  (1,6),(2,6)],
            'S': [(1,0),(2,0),(3,0),
                  (0,1),(0,2),
                  (1,3),(2,3),
                  (3,4),(3,5),
                  (0,6),(1,6),(2,6)],
            'M': [(0,0),(0,1),(0,2),(0,3),(0,4),(0,5),(0,6),
                  (1,1),
                  (2,2),
                  (3,1),
                  (4,0),(4,1),(4,2),(4,3),(4,4),(4,5),(4,6)],
            'G': [(1,0),(2,0),(3,0),
                  (0,1),(0,2),(0,3),(0,4),(0,5),
                  (2,3),(3,3),(3,4),(3,5),
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
        }
        return fonts.get(char.upper(), [])
    
    def display_text(self, text: str, start_x: int, start_y: int, color: str, timestamp: int):
        """Display text at specified position."""
        leds = []
        x_offset = 0
        
        for char in text:
            char_pixels = self.get_5x7_char(char)
            for dx, dy in char_pixels:
                led = xy_to_led(start_x + x_offset + dx, start_y + dy)
                if led >= 0:
                    leds.append(led)
            x_offset += 6  # 5 pixels + 1 space
        
        if leds:
            self.add_frame('set', timestamp, color=color, leds=leds)
    
    def add_flashing_text(self, text: str, start_x: int, start_y: int, start_time: int, hold_time: int):
        """Display text with flash sequence, hold, and fade."""
        # Flash sequence (3 flashes with increasing intensity)
        self.display_text(text, start_x, start_y, COLORS['deep_purple'], start_time)
        self.display_text(text, start_x, start_y, COLORS['dim_blue'], start_time + 100)
        self.display_text(text, start_x, start_y, COLORS['magenta'], start_time + 200)
        self.display_text(text, start_x, start_y, COLORS['dim_blue'], start_time + 300)
        self.display_text(text, start_x, start_y, COLORS['bright_magenta'], start_time + 400)
        
        # Hold in bright white
        self.display_text(text, start_x, start_y, COLORS['bright_white'], start_time + 500)
        
        # Fade out sequence
        fade_start = start_time + 500 + hold_time
        self.display_text(text, start_x, start_y, COLORS['white'], fade_start)
        self.display_text(text, start_x, start_y, COLORS['cyan'], fade_start + 200)
        self.display_text(text, start_x, start_y, COLORS['ice_blue'], fade_start + 400)
        self.display_text(text, start_x, start_y, COLORS['dim_blue'], fade_start + 600)
    
    # ============ COLUMN EFFECTS ============
    
    def add_column_sweep(self, start_x: int, end_x: int, color: str, start_time: int, duration: int):
        """Sweep columns from start to end."""
        step = 1 if end_x > start_x else -1
        columns = list(range(start_x, end_x + step, step))
        step_time = duration // len(columns)
        
        for i, x in enumerate(columns):
            leds = get_column_leds(x)
            self.add_frame('set', start_time + i * step_time, color=color, leds=leds)
    
    def add_ice_crystal_burst(self, corner: str, start_time: int):
        """Create ice crystal burst from corner."""
        # Define corner starting points
        corners = {
            'top_left': (0, 0),
            'top_right': (WIDTH-1, 0),
            'bottom_left': (0, HEIGHT-1),
            'bottom_right': (WIDTH-1, HEIGHT-1)
        }
        
        cx, cy = corners[corner]
        
        # Expand outward in waves
        for radius in range(1, 6):
            leds = []
            for dx in range(-radius, radius + 1):
                for dy in range(-radius, radius + 1):
                    if abs(dx) + abs(dy) == radius:  # Diamond pattern
                        led = xy_to_led(cx + dx, cy + dy)
                        if led >= 0:
                            leds.append(led)
            
            color = COLORS['bright_white'] if radius <= 2 else COLORS['ice_blue']
            self.add_frame('set', start_time + radius * 80, color=color, leds=leds)
    
    # ============ MAIN LIGHTSHOW GENERATOR ============
    
    def generate_wizards_in_winter(self):
        """Generate the complete Wizards in Winter lightshow."""
        # Song duration: 3:05 = 185 seconds = 185000ms
        duration_ms = 185000
        
        # Start with black screen
        self.add_frame('fill', 0, color=COLORS['black'])
        
        # ===== INTRO (0:00 - 0:15) - 15000ms =====
        # Single snowflake falling, building energy
        self.add_falling_snowflake(16, COLORS['white'], 500, 2000)
        self.add_quick_lightning_strike(8, 2500)
        self.add_falling_snowflake(24, COLORS['cyan'], 3000, 2000)
        self.add_quick_lightning_strike(20, 5000)
        
        # Column sweep building
        self.add_column_sweep(0, 15, COLORS['deep_purple'], 6000, 1500)
        self.add_column_sweep(31, 16, COLORS['magenta'], 6000, 1500)
        
        # Ice crystal bursts from corners
        self.add_ice_crystal_burst('top_left', 8000)
        self.add_ice_crystal_burst('top_right', 8500)
        
        # More snowflakes
        self.add_falling_snowflake(10, COLORS['ice_blue'], 10000, 2000)
        self.add_falling_snowflake(22, COLORS['white'], 11000, 2000)
        
        self.add_sustained_lightning(5, 13000, 1500)
        
        # ===== MAIN THEME SECTION 1 (0:15 - 0:45) - Fast energy =====
        # "WIZARDS" text display
        self.add_flashing_text("WIZARDS", 2, 0, 15000, 2000)
        
        # Rapid column sweeps (intense!)
        for i in range(5):
            start = 18000 + i * 1200
            self.add_column_sweep(0, 31, COLORS['ice_blue'], start, 600)
            self.add_column_sweep(31, 0, COLORS['purple'], start + 600, 600)
        
        # Lightning strikes mixed in
        self.add_quick_lightning_strike(10, 19000)
        self.add_quick_lightning_strike(22, 20500)
        self.add_sustained_lightning(16, 22000, 1000)
        
        # Multiple snowflakes falling
        self.add_falling_snowflake(8, COLORS['white'], 24000, 1800)
        self.add_falling_snowflake(16, COLORS['cyan'], 24500, 1800)
        self.add_falling_snowflake(24, COLORS['ice_blue'], 25000, 1800)
        
        # More column action
        for i in range(4):
            start = 27000 + i * 1500
            self.add_column_sweep(0, 15, COLORS['magenta'], start, 700)
            self.add_column_sweep(31, 16, COLORS['purple'], start, 700)
            self.add_quick_lightning_strike(8 + i * 6, start + 800)
        
        # Ice crystals
        self.add_ice_crystal_burst('bottom_left', 30000)
        self.add_ice_crystal_burst('bottom_right', 30500)
        
        # ===== BREAKDOWN SECTION (0:45 - 1:15) - Still intense but more magical =====
        # "WINTER" text
        self.add_flashing_text("WINTER", 3, 0, 45000, 2000)
        
        # More snowflakes (3-4 at once)
        self.add_falling_snowflake(6, COLORS['white'], 48000, 2500)
        self.add_falling_snowflake(14, COLORS['cyan'], 48300, 2500)
        self.add_falling_snowflake(22, COLORS['ice_blue'], 48600, 2500)
        self.add_falling_snowflake(28, COLORS['white'], 48900, 2500)
        
        # Sustained lightning
        self.add_sustained_lightning(10, 51000, 1500)
        self.add_sustained_lightning(20, 52000, 1500)
        
        # Alternating columns (creates ripple effect)
        for i in range(16):
            time = 54000 + i * 150
            even_cols = [get_column_leds(x) for x in range(0, WIDTH, 2)]
            odd_cols = [get_column_leds(x) for x in range(1, WIDTH, 2)]
            
            color = COLORS['purple'] if i % 2 == 0 else COLORS['ice_blue']
            cols = even_cols if i % 2 == 0 else odd_cols
            
            all_leds = []
            for col in cols:
                all_leds.extend(col)
            self.add_frame('set', time, color=color, leds=all_leds)
        
        # More snowflakes
        self.add_falling_snowflake(4, COLORS['cyan'], 57000, 2000)
        self.add_falling_snowflake(12, COLORS['white'], 57500, 2000)
        self.add_falling_snowflake(20, COLORS['ice_blue'], 58000, 2000)
        self.add_falling_snowflake(26, COLORS['white'], 58500, 2000)
        
        # Quick lightning strikes
        self.add_quick_lightning_strike(8, 60000)
        self.add_quick_lightning_strike(16, 60500)
        self.add_quick_lightning_strike(24, 61000)
        
        # Vortex effect (spiral columns)
        spiral_order = [15, 16, 14, 17, 13, 18, 12, 19, 11, 20, 10, 21, 9, 22, 8, 23]
        for i, x in enumerate(spiral_order):
            self.add_frame('set', 62000 + i * 100, color=COLORS['magenta'], leds=get_column_leds(x))
        
        # Ice crystal bursts
        self.add_ice_crystal_burst('top_left', 65000)
        self.add_ice_crystal_burst('bottom_right', 65500)
        
        # More snowflakes
        self.add_falling_snowflake(10, COLORS['white'], 67000, 2000)
        self.add_falling_snowflake(22, COLORS['cyan'], 67500, 2000)
        
        # ===== BUILD TO CLIMAX (1:15 - 1:45) =====
        # "MAGIC" text
        self.add_flashing_text("MAGIC", 5, 0, 75000, 2000)
        
        # Increasing intensity - faster sweeps
        for i in range(6):
            start = 78000 + i * 1000
            self.add_column_sweep(0, 31, COLORS['bright_magenta'], start, 500)
            self.add_column_sweep(31, 0, COLORS['cyan'], start + 500, 500)
        
        # Lightning storm building
        self.add_sustained_lightning(5, 79000, 1200)
        self.add_quick_lightning_strike(15, 80500)
        self.add_sustained_lightning(25, 82000, 1200)
        self.add_quick_lightning_strike(12, 83500)
        self.add_quick_lightning_strike(20, 84000)
        
        # Multiple snowflakes
        for i in range(5):
            x = 6 + i * 5
            self.add_falling_snowflake(x, COLORS['white'], 85000 + i * 400, 1800)
        
        # All corners ice burst
        self.add_ice_crystal_burst('top_left', 87000)
        self.add_ice_crystal_burst('top_right', 87200)
        self.add_ice_crystal_burst('bottom_left', 87400)
        self.add_ice_crystal_burst('bottom_right', 87600)
        
        # More rapid columns
        for i in range(8):
            start = 89000 + i * 700
            self.add_column_sweep(0, 31, COLORS['purple'], start, 350)
            self.add_column_sweep(31, 0, COLORS['ice_blue'], start + 350, 350)
        
        # ===== PEAK ENERGY (1:45 - 2:30) - EVERYTHING AT ONCE =====
        # "WIZARDS" again!
        self.add_flashing_text("WIZARDS", 2, 0, 105000, 2500)
        
        # Massive lightning storm
        self.add_sustained_lightning(8, 108000, 1500)
        self.add_sustained_lightning(16, 108300, 1500)
        self.add_sustained_lightning(24, 108600, 1500)
        
        # Ultra fast column sweeps
        for i in range(12):
            start = 110000 + i * 800
            self.add_column_sweep(0, 31, COLORS['bright_magenta'], start, 400)
            self.add_column_sweep(31, 0, COLORS['bright_white'], start + 400, 400)
        
        # Continuous snowflakes
        for i in range(8):
            x = 4 + i * 3
            self.add_falling_snowflake(x, COLORS['cyan'], 120000 + i * 500, 1500)
        
        # Lightning bursts
        for i in range(6):
            x = 5 + i * 4
            self.add_quick_lightning_strike(x, 124000 + i * 600)
        
        # "WINTER" text again
        self.add_flashing_text("WINTER", 3, 0, 128000, 2000)
        
        # More column madness
        for i in range(10):
            start = 131000 + i * 600
            self.add_column_sweep(0, 15, COLORS['ice_blue'], start, 300)
            self.add_column_sweep(31, 16, COLORS['magenta'], start, 300)
            self.add_column_sweep(15, 0, COLORS['purple'], start + 300, 300)
            self.add_column_sweep(16, 31, COLORS['cyan'], start + 300, 300)
        
        # All corners burst repeatedly
        for i in range(3):
            start = 138000 + i * 1000
            self.add_ice_crystal_burst('top_left', start)
            self.add_ice_crystal_burst('top_right', start + 200)
            self.add_ice_crystal_burst('bottom_left', start + 400)
            self.add_ice_crystal_burst('bottom_right', start + 600)
        
        # More snowflakes
        for i in range(6):
            x = 8 + i * 4
            self.add_falling_snowflake(x, COLORS['white'], 142000 + i * 400, 1600)
        
        # Lightning finale build
        self.add_sustained_lightning(6, 146000, 1000)
        self.add_sustained_lightning(16, 146500, 1000)
        self.add_sustained_lightning(26, 147000, 1000)
        
        # ===== PRE-FINALE (2:30 - 2:50) - Building to the end =====
        # Rapid everything
        for i in range(15):
            start = 150000 + i * 500
            if i % 3 == 0:
                self.add_quick_lightning_strike(10 + (i % 3) * 6, start)
            self.add_column_sweep(0, 31, COLORS['bright_magenta'], start, 250)
            self.add_column_sweep(31, 0, COLORS['cyan'], start + 250, 250)
        
        # Final snowflake cascade
        for i in range(10):
            x = 3 + i * 2
            self.add_falling_snowflake(x, COLORS['white'], 158000 + i * 300, 1200)
        
        # Final ice crystal bursts
        for i in range(4):
            corners = ['top_left', 'top_right', 'bottom_left', 'bottom_right']
            self.add_ice_crystal_burst(corners[i], 163000 + i * 300)
        
        # ===== FINALE (2:50 - 3:05) - Dark blue → blizzard → scroll text =====
        # Fade to dark blue
        self.add_frame('fill', 170000, color=COLORS['dark_blue'])
        self.add_frame('fill', 170500, color=COLORS['dim_blue'])
        
        # White pixel blizzard falling from top
        # Create multiple waves of white pixels falling
        for wave in range(12):
            wave_time = 171000 + wave * 200
            # Top row starts white
            top_leds = get_row_leds(0)
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

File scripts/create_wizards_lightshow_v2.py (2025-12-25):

#!/usr/bin/env python3
"""
Generate the Wizards in Winter lightshow JSON - IMPROVED VERSION
- Bold, readable text
- Persistent snowflakes that stay visible
- Beat-synced to actual audio analysis
"""

import json
from typing import List, Tuple

# LED Matrix configuration
WIDTH = 32
HEIGHT = 8
TOTAL_LEDS = 256

def xy_to_led(x: int, y: int) -> int:
    """Convert matrix coordinates to LED index for serpentine wiring."""
    if x < 0 or x >= WIDTH or y < 0 or y >= HEIGHT:
        return -1
    if x % 2 == 0:  # Even columns go DOWN (0→7)
        return x * HEIGHT + y
    else:           # Odd columns go UP (7→0)
        return x * HEIGHT + (HEIGHT - 1 - y)

def get_column_leds(x: int) -> List[int]:
    """Get all LED indices for a column."""
    return [xy_to_led(x, y) for y in range(HEIGHT) if xy_to_led(x, y) >= 0]

def get_row_leds(y: int) -> List[int]:
    """Get all LED indices for a row."""
    return [xy_to_led(x, y) for x in range(WIDTH) if xy_to_led(x, y) >= 0]

# Winter magic color palette
COLORS = {
    'ice_blue': '#0099FF',
    'deep_blue': '#0066CC',
    'dark_blue': '#003366',
    'purple': '#9900CC',
    'deep_purple': '#6600CC',
    'magenta': '#CC00CC',
    'bright_magenta': '#FF00CC',
    'white': '#CCCCCC',
    'bright_white': '#FFFFFF',
    'cyan': '#00CCCC',
    'dim_blue': '#002244',
    'black': '#000000'
}

class LightshowGenerator:
    def __init__(self, beat_data):
        self.frames = []
        self.current_time = 0
        self.beat_data = beat_data
        self.beats = beat_data['beat_times_ms']
        self.strong_beats = beat_data['strong_beats_ms']
        
    def add_frame(self, effect: str, timestamp_ms: int = None, **kwargs):
        """Add a frame to the lightshow."""
        if timestamp_ms is not None:
            self.current_time = timestamp_ms
        
        frame = {
            'timestampMs': self.current_time,
            'effect': effect
        }
        frame.update(kwargs)
        self.frames.append(frame)
    
    def advance_time(self, ms: int):
        """Advance the current timestamp."""
        self.current_time += ms
    
    # ============ SNOWFLAKE PATTERNS ============
    
    def get_snowflake_6point(self, center_x: int, center_y: int) -> List[int]:
        """
        Create an intricate 6-point snowflake pattern.
        Size: approximately 7x7 pixels
        """
        offsets = [
            # Center (make it brighter/more visible)
            (0, 0),
            # Main 6 arms (vertical and diagonals)
            (0, -1), (0, -2), (0, -3),  # Top arm
            (0, 1), (0, 2), (0, 3),      # Bottom arm
            (-1, -1), (-2, -2),          # Top-left diagonal
            (1, -1), (2, -2),            # Top-right diagonal
            (-1, 1), (-2, 2),            # Bottom-left diagonal
            (1, 1), (2, 2),              # Bottom-right diagonal
            # Branch tips (make it intricate)
            (-1, -2), (1, -2),           # Top arm branches
            (-1, 2), (1, 2),             # Bottom arm branches
            (-2, -1), (-2, 0), (-2, 1),  # Left arm
            (2, -1), (2, 0), (2, 1),     # Right arm
            # Extra detail points
            (-1, 0), (1, 0),             # Horizontal extensions
        ]
        
        leds = []
        for dx, dy in offsets:
            led = xy_to_led(center_x + dx, center_y + dy)
            if led >= 0:
                leds.append(led)
        return list(set(leds))  # Remove duplicates
    
    def add_persistent_snowflake(self, start_x: int, color: str, start_time: int, stay_duration: int):
        """
        Animate a snowflake that STAYS VISIBLE for a long time.
        Falls slowly, then stays in place for the duration before fading.
        """
        # Fall phase (quick, 1 second)
        fall_duration = 1000
        steps = HEIGHT - 2  # Fall from y=1 to y=6 (leave room at bottom)
        step_time = fall_duration // steps
        
        # Falling animation
        for step in range(steps + 1):
            y = step + 1  # Start at y=1
            if y < HEIGHT - 1:
                leds = self.get_snowflake_6point(start_x, y)
                self.add_frame('set', start_time + step * step_time, color=color, leds=leds)
                
                # Dim previous position slightly (not completely remove)
                if step > 0:
                    prev_leds = self.get_snowflake_6point(start_x, step)
                    self.add_frame('set', start_time + step * step_time + 30, 
                                 color=COLORS['dim_blue'], leds=prev_leds)
        
        # STAY phase - snowflake remains visible
        final_y = min(steps + 1, HEIGHT - 2)
        final_leds = self.get_snowflake_6point(start_x, final_y)
        
        # Keep it bright and visible
        stay_start = start_time + fall_duration
        self.add_frame('set', stay_start, color=color, leds=final_leds)
        self.add_frame('set', stay_start + stay_duration // 2, color=color, leds=final_leds)
        
        # Gentle fade out at the end (gradual, not instant)
        fade_start = stay_start + stay_duration
        self.add_frame('set', fade_start, color=COLORS['ice_blue'], leds=final_leds)
        self.add_frame('set', fade_start + 300, color=COLORS['deep_blue'], leds=final_leds)
        self.add_frame('set', fade_start + 600, color=COLORS['dim_blue'], leds=final_leds)
    
    # ============ STEPPING ANIMATIONS (Piano Solos) ============
    
    def add_stepping_animation(self, start_time: int, duration: int, direction: str = 'up'):
        """
        Create stepping/staircase animation - perfect for piano solos.
        Pixels light up in a cascading staircase pattern.
        """
        step_time = 80  # Time per step in ms
        steps = duration // step_time
        
        for step in range(steps):
            timestamp = start_time + step * step_time
            
            # Create diagonal stepping pattern
            leds = []
            for offset in range(5):  # 5 diagonals visible at once
                if direction == 'up':
                    y = (step + offset) % HEIGHT
                    x = ((step + offset) * 2) % WIDTH
                else:  # down
                    y = HEIGHT - 1 - ((step + offset) % HEIGHT)
                    x = ((step + offset) * 2) % WIDTH
                
                # Light up 2-3 columns for each step
                for dx in range(3):
                    if x + dx < WIDTH:
                        led = xy_to_led(x + dx, y)
                        if led >= 0:
                            leds.append(led)
            
            # Alternate colors for visual interest
            colors = [COLORS['ice_blue'], COLORS['cyan'], COLORS['white'], COLORS['magenta']]
            color = colors[(step // 4) % len(colors)]
            
            if leds:
                self.add_frame('set', timestamp, color=color, leds=leds)
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

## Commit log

2025-12-23 First set of files for the nutcracker
    [nutcracker-enclosure.scad]
2025-12-23 Working on the 3d model for the box
    [nutcracker-enclosure.scad]
2025-12-23 Added matrix dimensions and recalculated the display plaque
    [nutcracker-enclosure.scad]
2025-12-23 Implement LED service with initialization, pattern playback, and mock mode for non-Raspberry Pi environments
2025-12-23 Refactor LedService to use SPI for WS2812B initialization and update README with GPIO pin change
2025-12-23 Refactor ReconnectModal and LedService for improved functionality and configuration
2025-12-23 Add remote deployment target for Raspberry Pi
2025-12-23 Add native rpi_ws281x library support and enhance LED control functionality
    - Introduced P/Invoke wrapper for the rpi_ws281x library to control WS2812B LED strips directly from C#.
    - Updated LedService to utilize the native library for LED control, improving performance and reliability.
    - Added deployment instructions for Raspberry Pi in DEPLOYMENT.md.
    - Implemented a skip feature in LightshowService to allow users to skip the current lightshow.
    - Enhanced Home.razor with a skip button for user interaction.
    - Created installation scripts for the native library and LED drivers.
    - Added a Python LED driver script for testing and controlling the LED matrix.
    - Updated CSS for improved button sty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
    [led_driver.py, led_matrix_test.py]
2025-12-23 feat: Add new test section styles and button animations in app.css
    refactor: Update merry-christmas-static.json for scrolling text effect
    build: Create deploy.ps1 script for deploying Nutcracker to Raspberry Pi
    fix: Enhance install_native_led_library.sh to create shared library if needed
    test: Revamp led_matrix_test.py for SPI control and improved patterns
    docs: Add raspberry-pi-gpio-diagram.md for WS2812B LED strip connections
    chore: Create set_capabilities.sh to set Linux capabilities for LED control
    [led_matrix_test.py]
2025-12-24 feat: Add LED brightness control feature with UI and service integration
2025-12-24 Implement full "MERRY CHRISTMAS" scrolling text with optimized LED pattern playback
    - Added create_merry_christmas_scrolling.py to generate scrolling text pattern
    - Implemented serpentine wiring support for LED matrix
    - Created a 3x5 pixel font for rendering letters
    - Optimized frame generation to reduce blinking during playback
    - Documented changes in SESSION-NOTES.md
2025-12-24 Add lightshow generation script and beat data for "Santa Claus Is Comin' To Town"
    - Created `create_bruce_lightshow.py` to analyze audio and generate LED lightshow frames based on detected beats and energy levels.
    - Added `beat_data.json` containing beat timings and total beat count for the song.
2025-12-24 Enhance lightshow effects with smoother transitions and improved timing
    - Implemented smoother transitions for beat-synced animations.
    - Added a delay to avoid effects occurring too close together.
    - Adjusted pulse effects for bottom and top rows to be less abrupt.
    - Modified big visual effects to occur every 16 beats instead of 8.
    - Changed column sweep effect to a wave effect with progressive lighting.
    - Increased energy threshold for alternating column effects during high energy sections.
    [create_bruce_lightshow.py]
2025-12-24 Refactor Nutcracker enclosure design for Raspberry Pi 3B compatibility, add mounting holes, and enhance curved display features. Introduce audio analysis scripts for Santa Claus song to identify chor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
    [nutcracker-enclosure.scad]
2025-12-25 Refactor code structure and remove redundant sections for improved readability and maintainability
    [emergency-led-plaque.scad, emergency-led-plaque.stl, emergency-platform-base - Copy.stl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]
2025-12-29 Organized the folder a bit
    [emergency-led-plaque.scad, emergency-led-plaque.stl, emergency-platform-base - Copy.stl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]
